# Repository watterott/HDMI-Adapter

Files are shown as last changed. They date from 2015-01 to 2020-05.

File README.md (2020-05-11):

# HDMI-Adapter
Universal HDMI/DVI Displays with Touch Panel based on an Adapter with TI TFP401 and Microchip ATmega32u4.

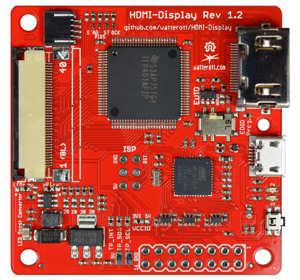
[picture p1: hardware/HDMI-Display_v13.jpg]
HDMI-Adapter


* [TI TFP401A](https://www.ti.com/product/TFP401A) HDMI to RGB Converter
* HDMI compatible (DVI, no Sound, no HDCP, no CEC)
* [Microchip ATmega32U4](https://www.microchip.com/wwwproducts/en/ATMEGA32U4) Microcontroller to control Backlight and Touch Panel (USB HID Mouse)
* LED Backlight Boost Regulator (up to 35V)
* Single 5V Power Supply via MicroUSB connector
* Open-Source and released under the [Creative Commons Attribution Share-Alike License](https://creativecommons.org/licenses/by-sa/4.0/).
* **[Documentation on learn.watterott.com](https://learn.watterott.com)**

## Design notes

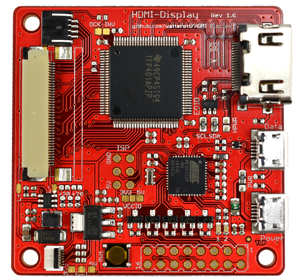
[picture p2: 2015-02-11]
hardware/HDMI-Display_v10.jpg

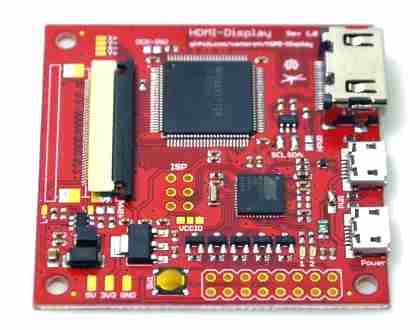
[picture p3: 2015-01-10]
hardware/HDMI-Display_v10dev.jpg

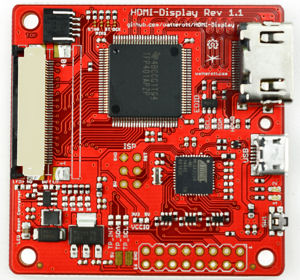
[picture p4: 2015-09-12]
hardware/HDMI-Display_v11.jpg

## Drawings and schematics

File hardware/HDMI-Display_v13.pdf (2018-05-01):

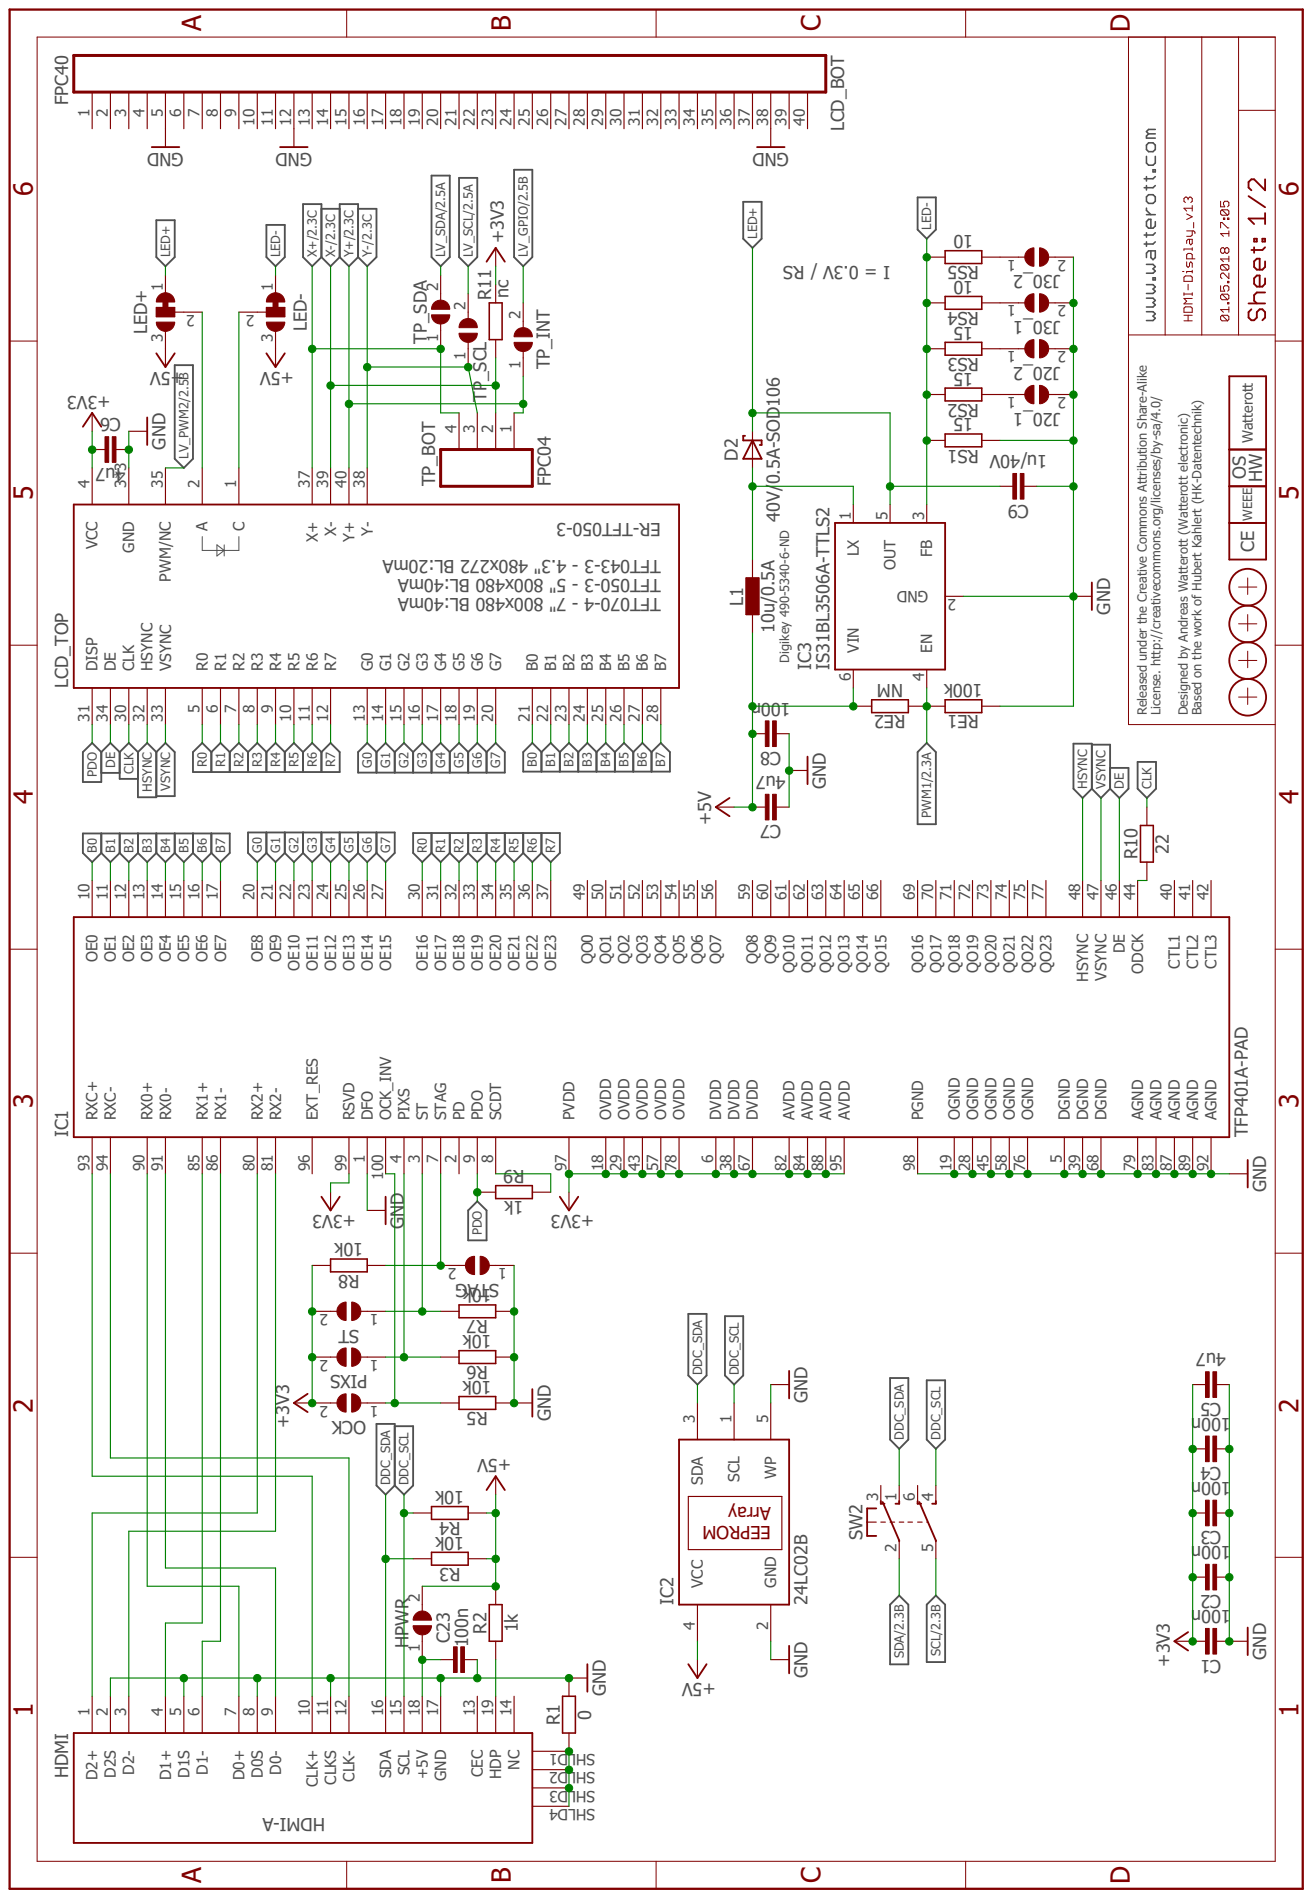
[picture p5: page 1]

Released under the Creative Commons Attribution Share-Alike

License. http://creativecommons.org/licenses/by-sa/4.0/ Designed by Andreas Watterott (Watterott electronic) Based on the work of Hubert Kahlert (HK-Datentechnik)

Watterott WEEE CE OS HW

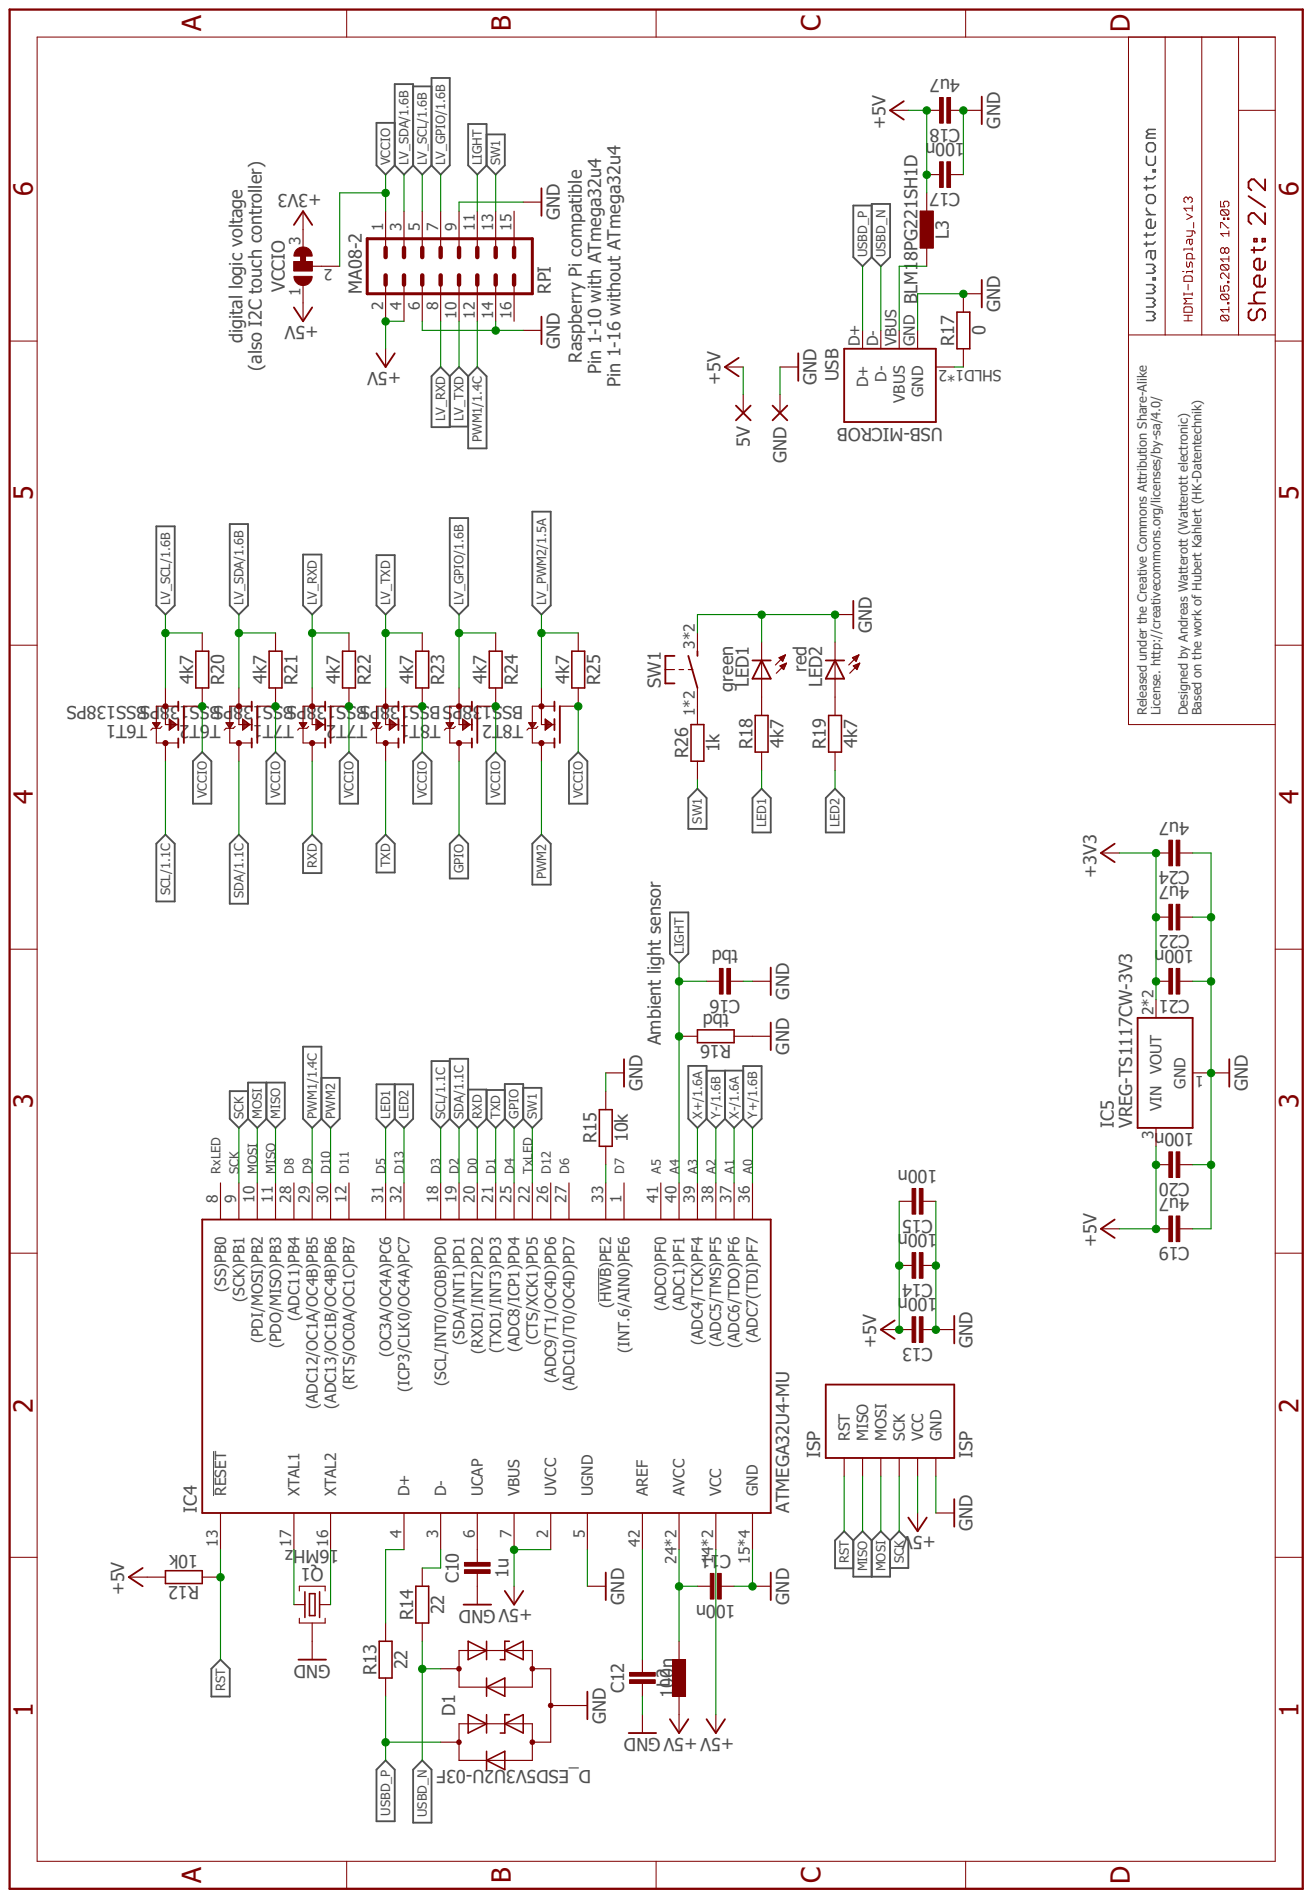
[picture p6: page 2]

mbient light sensor Raspberry Pi compatible Pin 1-10 with ATmega32u4 Pin 1-16 without ATmega32u4

Released under the Creative Commons Attribution Share-Alike

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

ST MISO MOSI SCK VCC GND

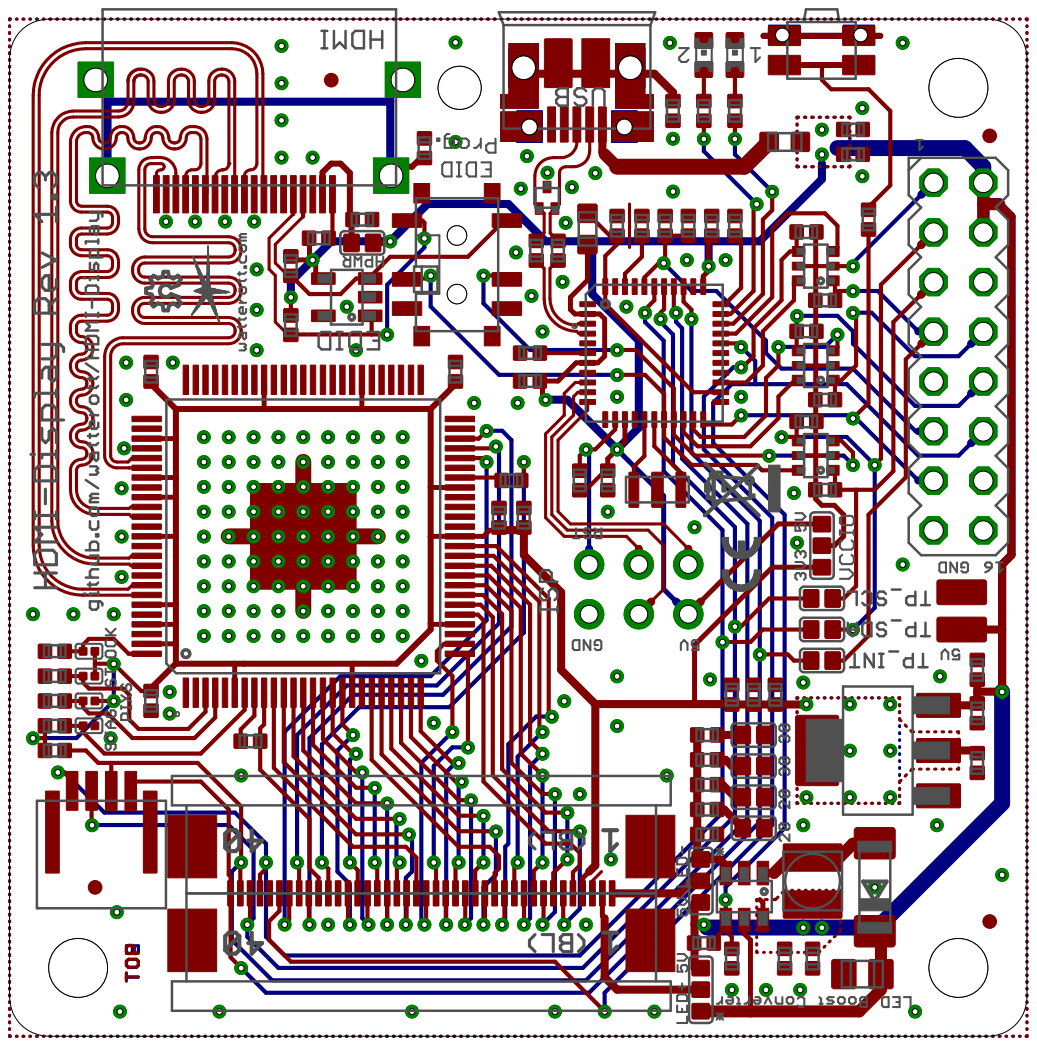
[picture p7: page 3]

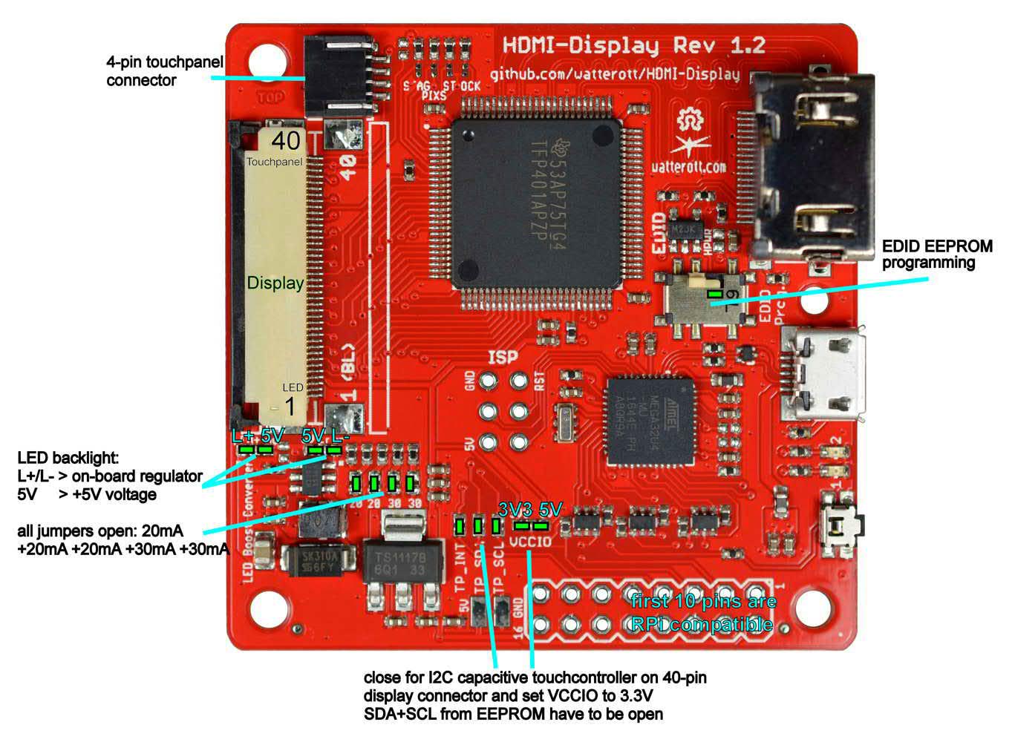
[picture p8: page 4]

Jumper | LED+ LED- VCCIO TP_SDA TP_SCL TP_INT
Displays with resistive Touchpanel
(no Backlight Boost Regulator) | LED+ LED-

3.3V
or
5V
open | open | open

Displays with capacitive Touchpanel
(on-board Backlight Boost Regulator) | 5V | 5V | 3.3V | closed | closed closed

The adapter is pre-programmed with the respective firmware for a resistive (RTP) or capacitive (CTP) Touchpanel. But the EDID EEPROM is empty.
To program EDID data into the EEPROM the switch has to be set to the marked direction and HDMI has to be disconnected during the programming. The programming can be started, when the tactile switch SW1 is hold on power-up.

The backlight brightness of the Displays with capacitive Touchpanel can be controlled via Pin 35 (AVR PB6).

Displays with resistive Touchpanel: TFT043-3, TFT050-3, TFT070-4

Displays with capacitive Touchpanel: HY050CTP-HD, HY070CTP, HY070CTP-HD, HY101CTP

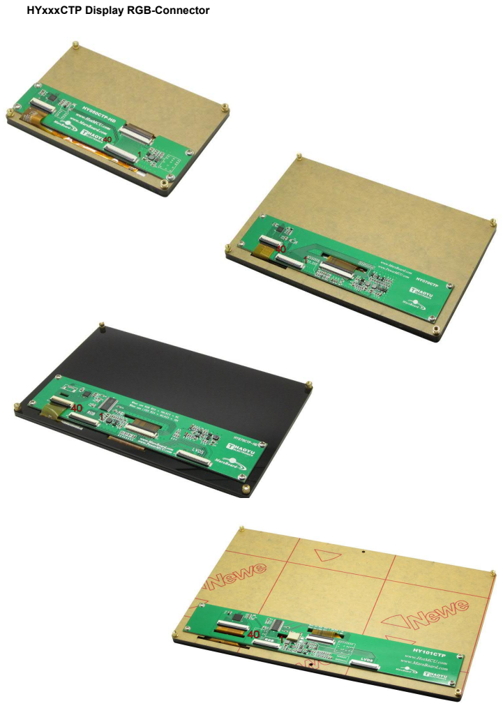
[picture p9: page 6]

HYxxxCTP Display RGB-Connector

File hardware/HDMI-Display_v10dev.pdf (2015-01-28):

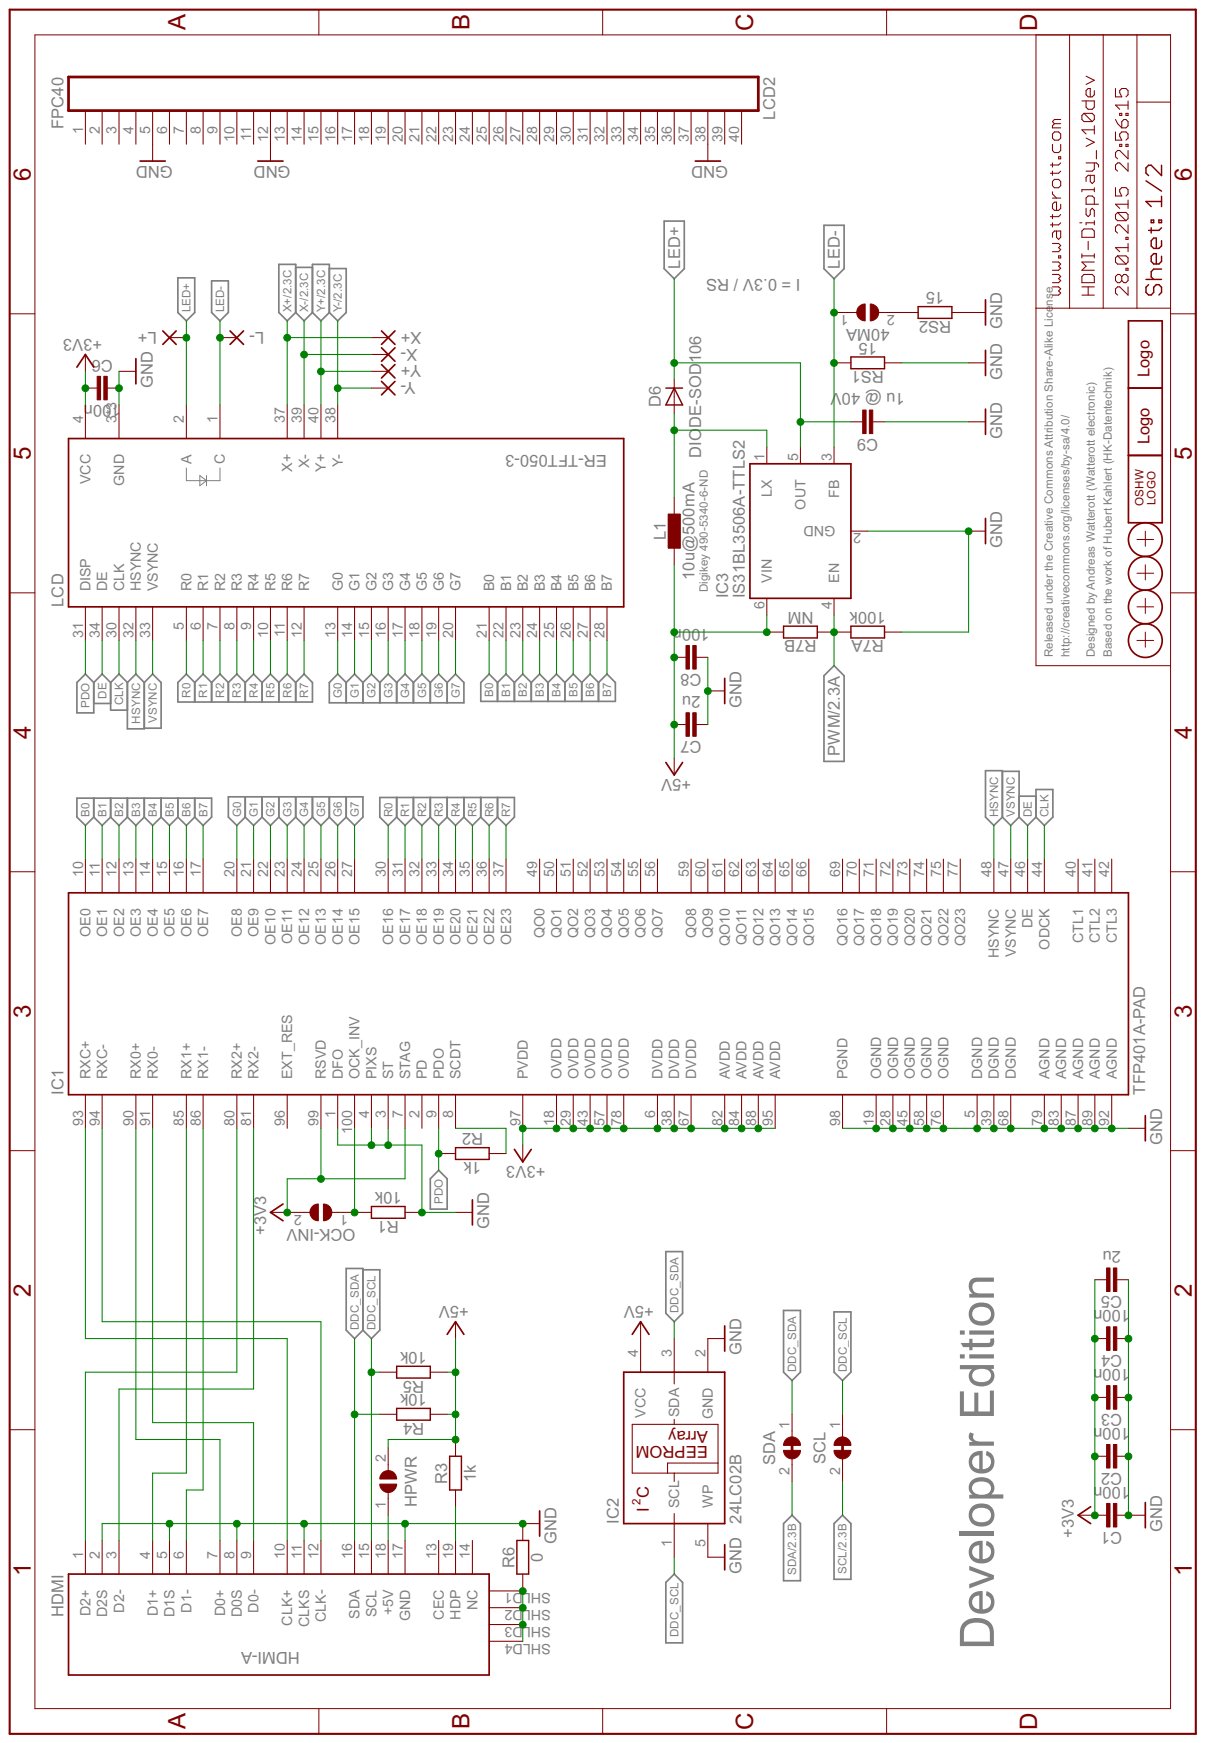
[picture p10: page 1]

Released under the Creative Commons Attribution Share-Alike License

Based on the work of Hubert Kahlert (HK-Datentechnik)

Designed by Andreas Watterott (Watterott electronic)

http://creativecommons.org/licenses/by-sa/4.0/

VSYNC 33 HSYNC 32 CLK 30 DE 34

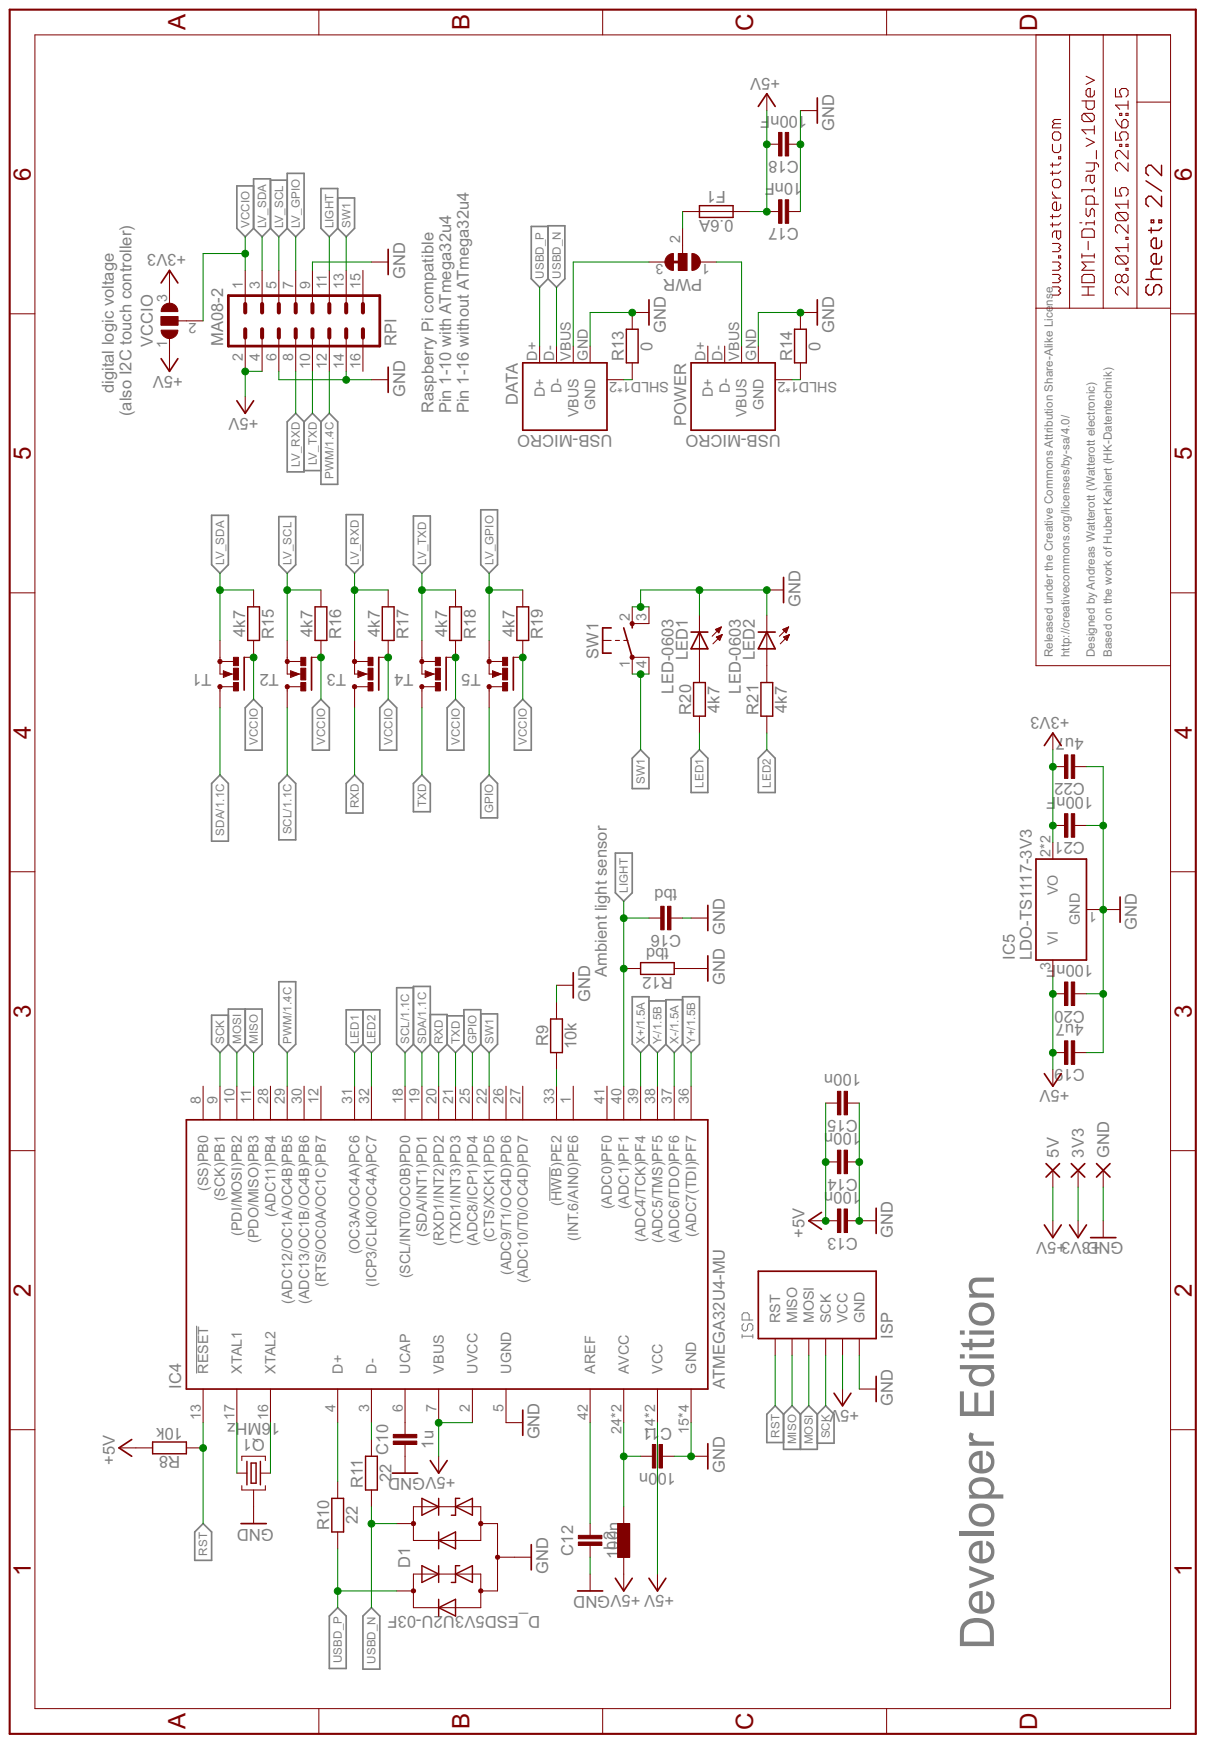
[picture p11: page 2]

(PDO/MISO)PB3 11 (PDI/MOSI)PB2 10 (SCK)PB1 9 (SS)PB0 8

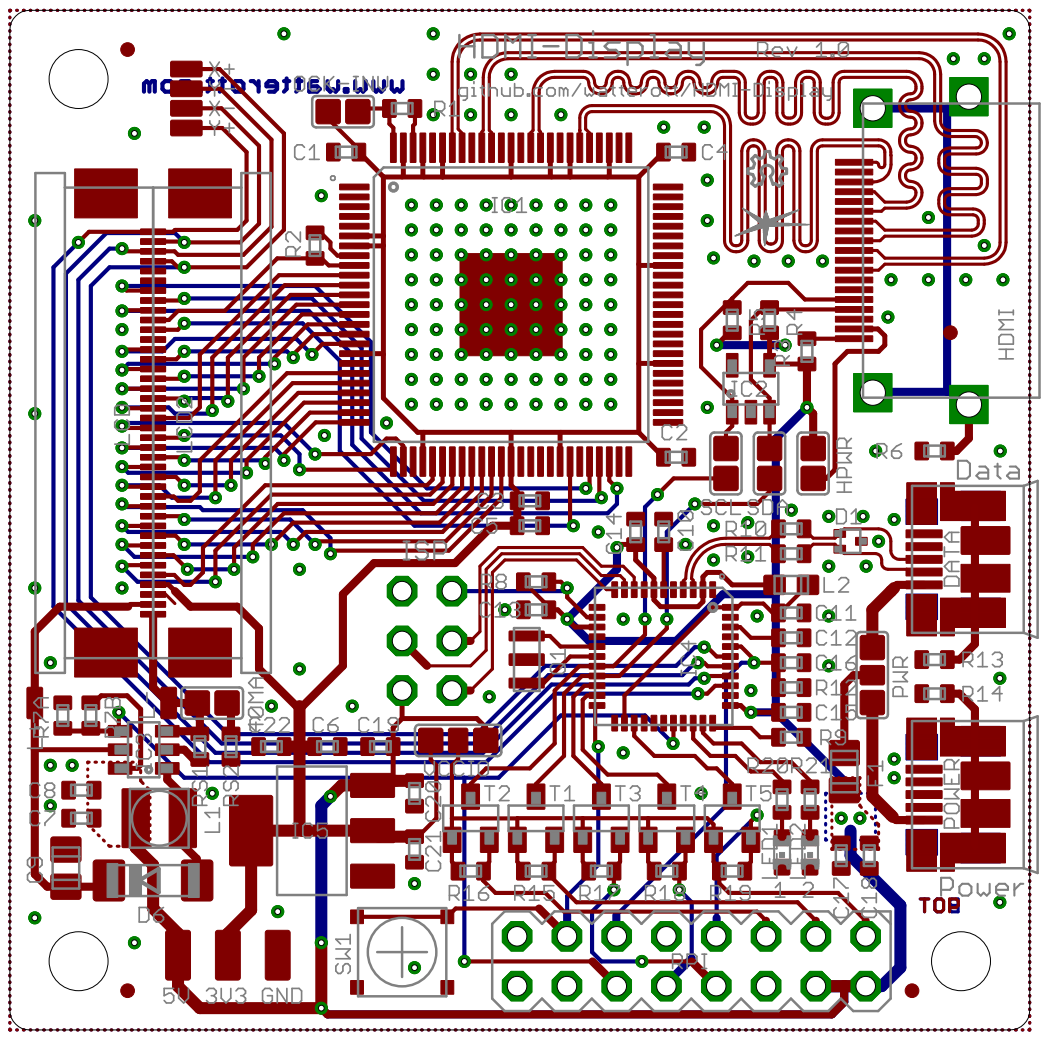
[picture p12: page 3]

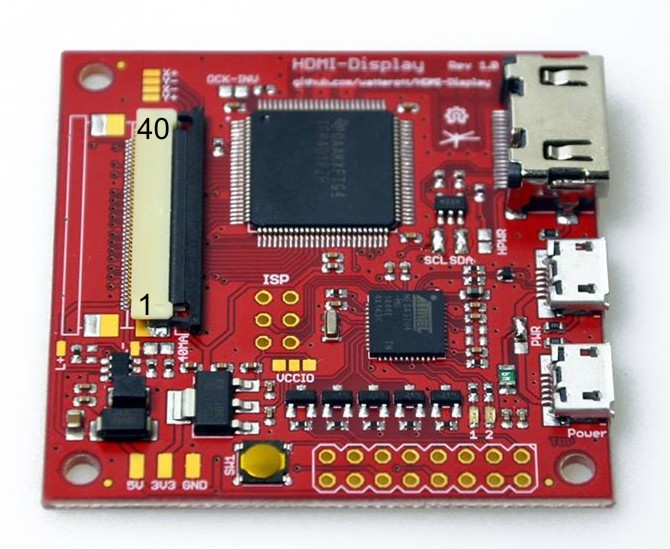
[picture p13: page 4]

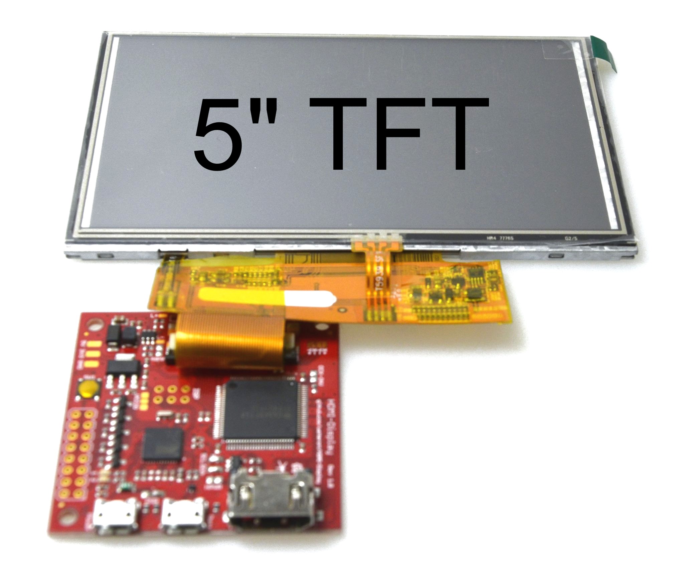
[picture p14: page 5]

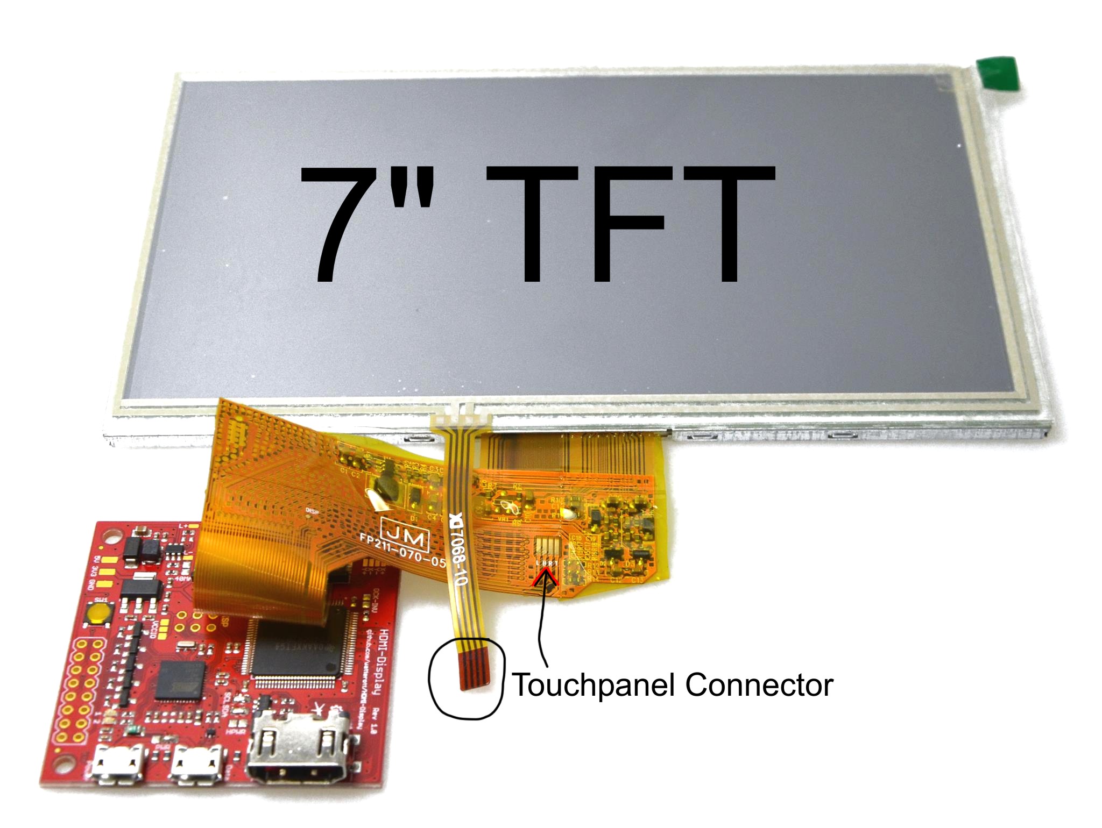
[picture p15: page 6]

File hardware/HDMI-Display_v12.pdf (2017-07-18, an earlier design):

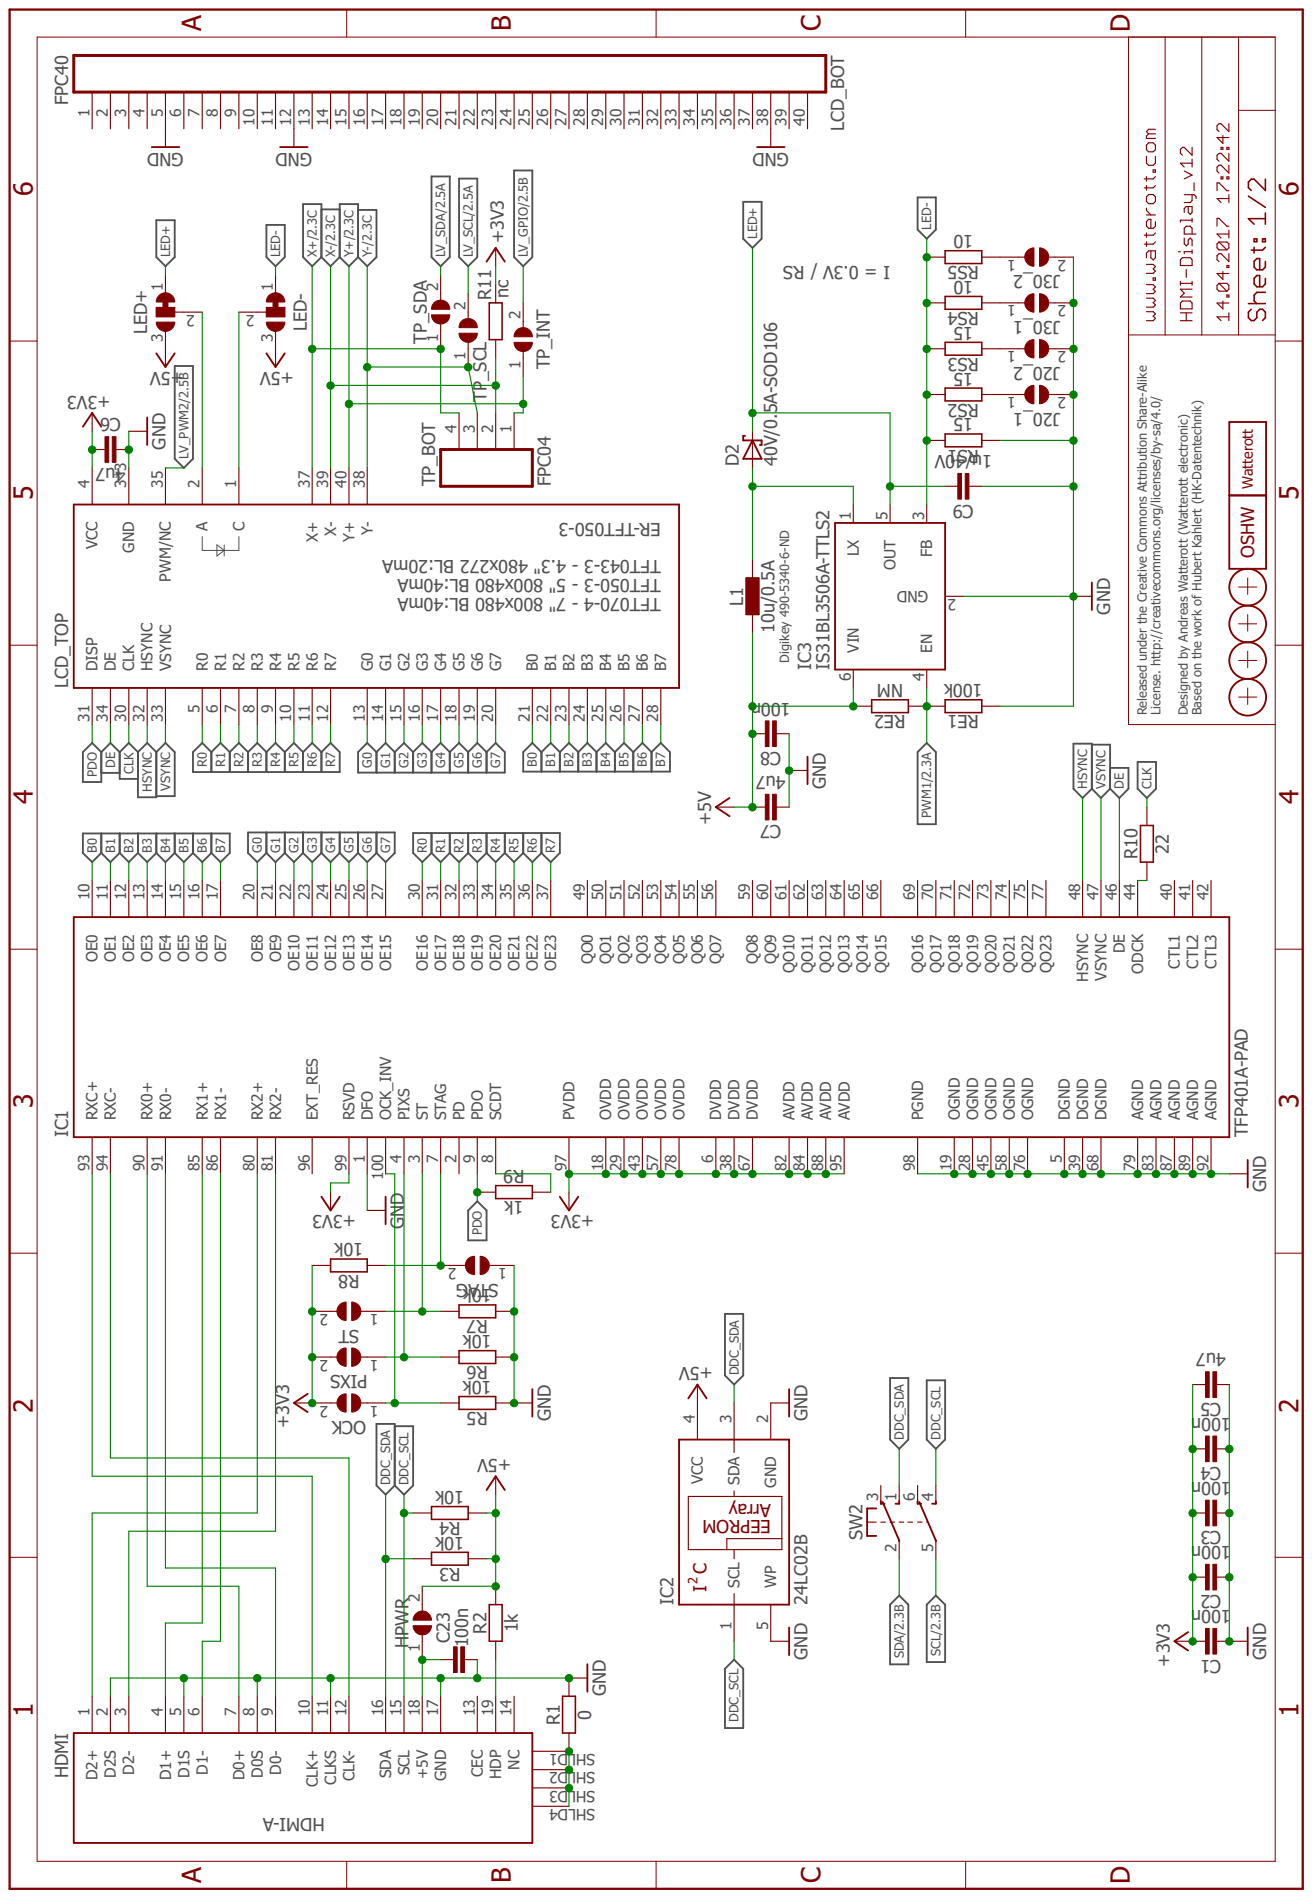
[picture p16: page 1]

Released under the Creative Commons At ribution Share-Alike

License. http://creativecommons.org/licenses/by-sa/4.0/ Designed by Andreas Watterott (Watterott electronic) Based on the work of Hubert Kahlert (HK-Datentechnik)


mbient light sensor Raspberry Pi compatible Pin 1-10 with ATmega32u4 Pin 1-16 without ATmega32u4

Released under the Creative Commons At ribution Share-Alike License http://creativecommons.org/licenses/by-sa/4.0/ Designed by Andreas Watterott (Watterott electronic) Based on the work of Hubert Kahlert (HK-Datentechnik)

ST MISO MOSI SCK VCC GND



Jumper | LED+ LED- VCCIO TP_SDA TP_SCL TP_INT
Displays with resistive Touchpanel
(no Backlight Boost Regulator) | LED+ LED-

3.3V
or
5V
open | open | open

Displays with capacitive Touchpanel
(on-board Backlight Boost Regulator) | 5V | 5V | 3.3V | closed | closed closed

The adapter is pre-programmed with the respective firmware for a resistive (RTP) or capacitive (CTP) Touchpanel. But the EDID EEPROM is empty.
To program EDID data into the EEPROM the switch has to be set to the marked direction and HDMI has to be disconnected during the programming. The programming can be started, when the tactile switch SW1 is hold on power-up.

The backlight brightness of the Displays with capacitive Touchpanel can be controlled via Pin 35 (AVR PB6).

Displays with resistive Touchpanel: TFT043-3, TFT050-3, TFT070-4

Displays with capacitive Touchpanel: HY050CTP-HD, HY070CTP, HY070CTP-HD, HY101CTP


HYxxxCTP Display RGB-Connector

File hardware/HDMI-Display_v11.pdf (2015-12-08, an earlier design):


Released under the Creative Commons Attribution Share-Alike License http://creativecommons.org/licenses/by-sa/4.0/ Designed by Andreas Watterott (Watterott electronic) Based on the work of Hubert Kahlert (HK-Datentechnik)


Raspberry Pi compatible Pin 1-10 with ATmega32u4 Pin 1-16 without ATmega32u4

GND USB ORCI M- BS U

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

ST MISO MOSI SCK VCC GND



Jumper | LED+ LED- VCCIO TP_SDA TP_SCL TP_INT

# Displays with resistive Touchpanel

(no Backlight Boost Regulator) | LED+ LED-

3.3V
or
5V
open | open | open

# Displays with capacitive Touchpanel

(on-board Backlight Boost Regulator) | 5V | 5V | 3.3V | closed | closed closed

# To program EDID data into the EEPROM the jumpers SDA + SCL have to be closed and

HDMI has to be disconnected during the programming.

# The backlight brightness of the Displays with capacitive Touchpanel can be controlled via

Pin 35 (AVR PB6).

# Displays with resistive Touchpanel: TFT043-3, TFT050-3, TFT070-4

Displays with capacitive Touchpanel: HY050CTP-HD, HY070CTP, HY070CTP-HD,

# HY101CTP


HYxxxCTP Display RGB-Connector

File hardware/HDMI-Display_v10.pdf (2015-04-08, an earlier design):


Released under the Creative Commons Attribution Share-Alike License

Based on the work of Hubert Kahlert (HK-Datentechnik)

Designed by Andreas Watterott (Watterott electronic)

http://creativecommons.org/licenses/by-sa/4.0/

VSYNC 33 HSYNC 32 CLK 30 DE 34


(PDO/MISO)PB3 11 (PDI/MOSI)PB2 10 (SCK)PB1 9 (SS)PB0 8





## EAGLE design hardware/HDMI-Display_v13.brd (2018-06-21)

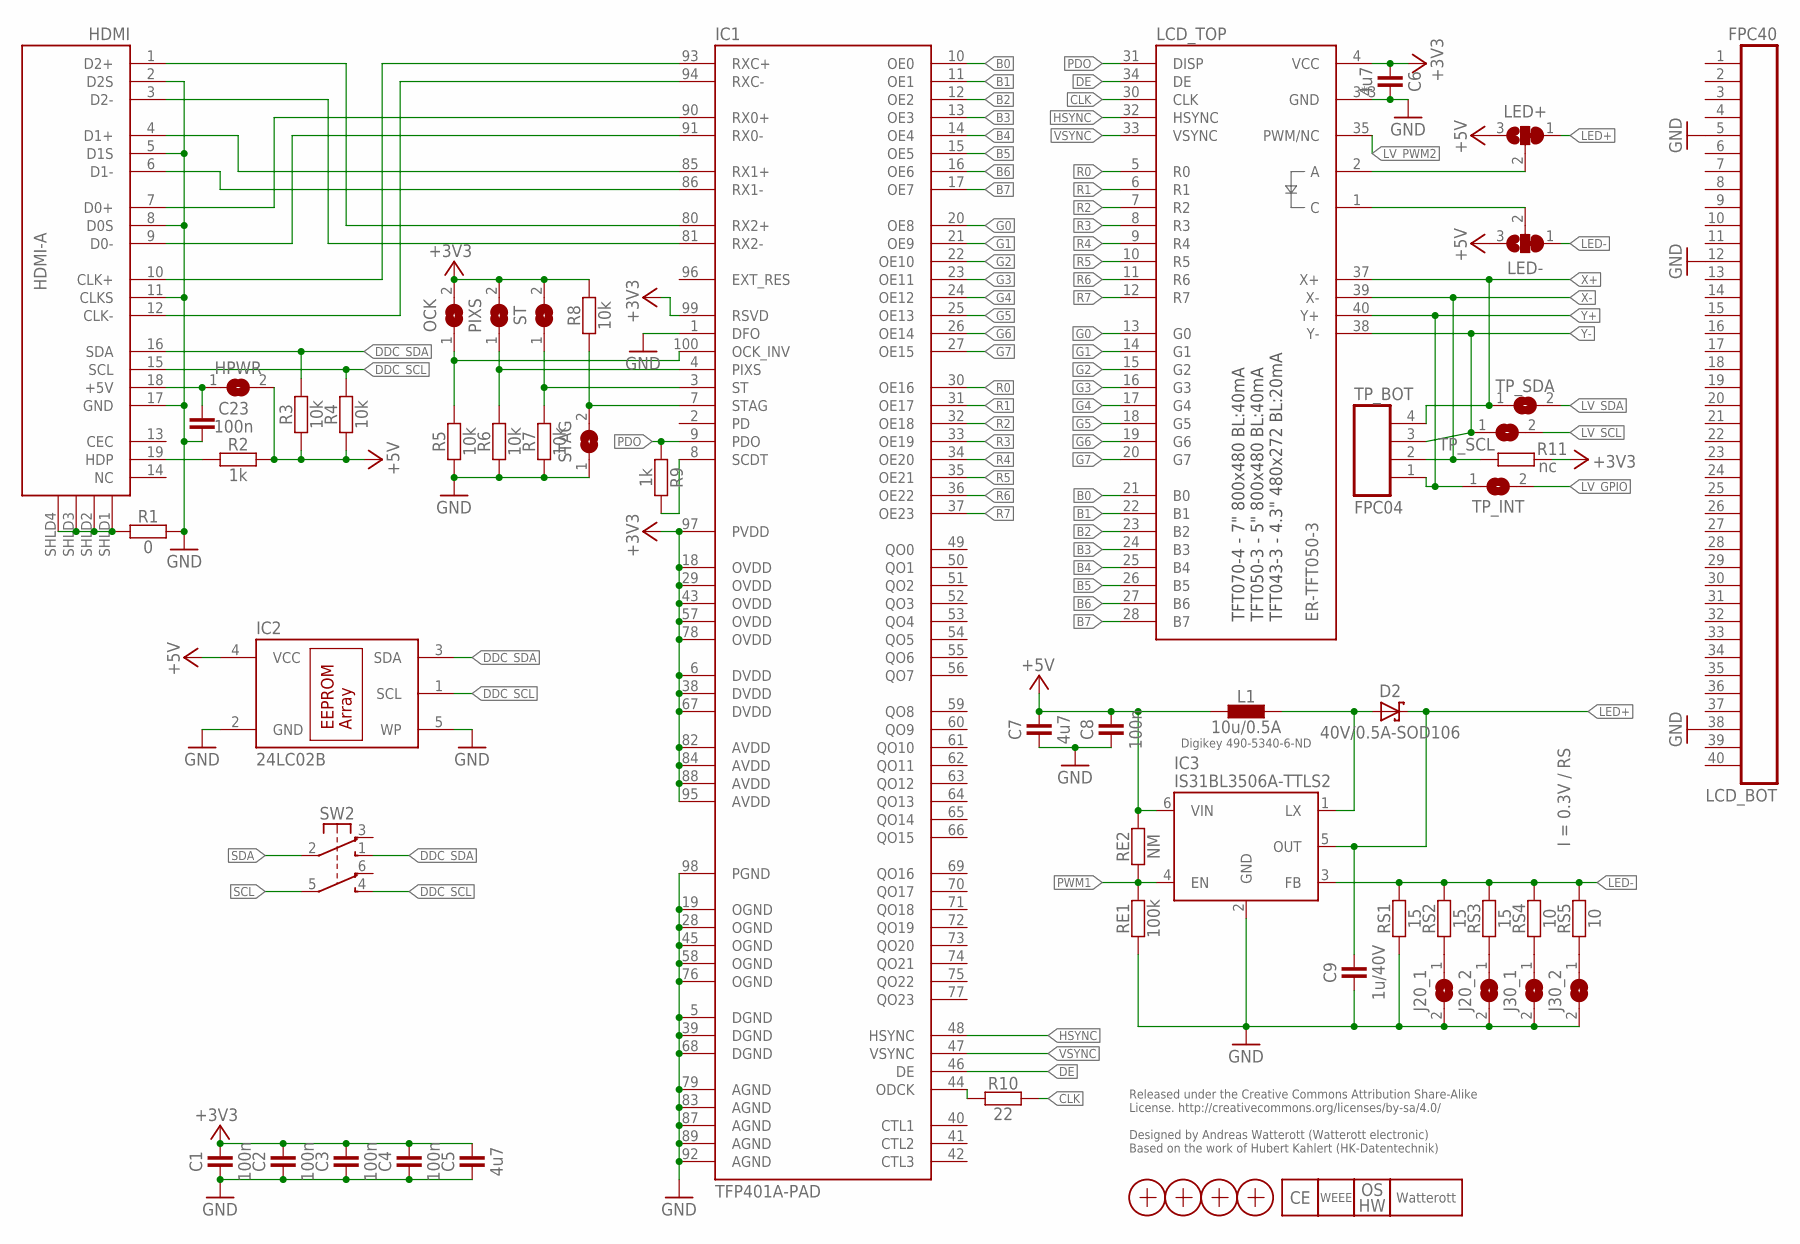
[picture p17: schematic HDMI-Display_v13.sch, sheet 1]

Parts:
C1, C2, C3, C4, C8, C23: 100n; C0402
C5, C6, C7: 4u7; C0402
C9: 1u/40V; C0805
D2: 40V/0.5A-SOD106; SOD106
HDMI: HDMI-A; HDMI_10029449
HPWR: JUMPER2-0402
IC1: TFP401A-PAD; TQFP100-PAD
IC2: 24LC02B; SOT23-5
IC3: IS31BL3506A-TTLS2; SOT23-6
J20_1, J20_2, J30_1, J30_2: JUMPER2-0402
L1: 10u/0.5A; L_1212
LCD_BOT: FPC40; FPC40-0.5
LCD_TOP: ER-TFT050-3; FPC40
LED+: JUMPER3-0402
LED-: JUMPER3-0402
LOGO2: LOGO_SPARK-2; SPARK_2MM
LOGO4: LOGO_WEEE-4; WEEE_4MM
LOGO5: LOGO_CE-2; CE_2MM
LOGO6: LOGO_OSHW-2; OSHW_2MM
OCK: JUMPER2-0201-NC; JUMPER2-0201_NC
PIXS: JUMPER2-0201-NC; JUMPER2-0201_NC
R1: 0; C0402
R2, R9: 1k; C0402
R3, R4, R5, R6, R7, R8: 10k; C0402
R10: 22; C0402
R11: nc; C0402
RE1: 100k; C0402
RE2: NM; C0402
RS1, RS2, RS3: 15; C0402
RS4, RS5: 10; C0402
ST: JUMPER2-0201-NC; JUMPER2-0201_NC
STAG: JUMPER2-0201-NC; JUMPER2-0201_NC
SW2: SW-2UM-CUS22B; CUS22B
TP_BOT: FPC04; FPC04-1.0
TP_INT: JUMPER2-0402
TP_SCL: JUMPER2-0402
TP_SDA: JUMPER2-0402
X1, X2, X3, X4: PASSER-07; PASSER_07MM

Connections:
+3V3: C1.2, C2.2, C3.2, C4.2, C5.2, C6.1, IC1.6 (DVDD), IC1.18 (OVDD), IC1.29 (OVDD), IC1.38 (DVDD), IC1.43 (OVDD), IC1.57 (OVDD), IC1.67 (DVDD), IC1.78 (OVDD), IC1.82 (AVDD), IC1.84 (AVDD), IC1.88 (AVDD), IC1.95 (AVDD), IC1.97 (PVDD), IC1.99 (RSVD), LCD_TOP.4 (VCC), OCK.2, PIXS.2, R8.2, R11.2, ST.2; also elsewhere on the board
+5V: C7.2, C8.2, HPWR.2, IC2.4 (VCC), IC3.6 (VIN), L1.1, LED+.3, LED-.3, R2.2, R3.1, R4.1, RE2.2; also elsewhere on the board
B0: IC1.10 (OE0), LCD_TOP.21 (B0)
B1: IC1.11 (OE1), LCD_TOP.22 (B1)
B2: IC1.12 (OE2), LCD_TOP.23 (B2)
B3: IC1.13 (OE3), LCD_TOP.24 (B3)
B4: IC1.14 (OE4), LCD_TOP.25 (B4)
B5: IC1.15 (OE5), LCD_TOP.26 (B5)
B6: IC1.16 (OE6), LCD_TOP.27 (B6)
B7: IC1.17 (OE7), LCD_TOP.28 (B7)
CLK: LCD_TOP.30 (CLK), R10.2
CLK_N: HDMI.12 (CLK-), IC1.94 (RXC-)
CLK_P: HDMI.10 (CLK+), IC1.93 (RXC+)
D0_N: HDMI.9 (D0-), IC1.91 (RX0-)
D0_P: HDMI.7 (D0+), IC1.90 (RX0+)
D1_N: HDMI.6 (D1-), IC1.86 (RX1-)
D1_P: HDMI.4 (D1+), IC1.85 (RX1+)
D2_N: HDMI.3 (D2-), IC1.81 (RX2-)
D2_P: HDMI.1 (D2+), IC1.80 (RX2+)
DDC_SCL: HDMI.15 (SCL), IC2.1 (SCL), R4.2, SW2.4 (S2)
DDC_SDA: HDMI.16 (SDA), IC2.3 (SDA), R3.2, SW2.1 (S1)
DE: IC1.46 (DE), LCD_TOP.34 (DE)
G0: IC1.20 (OE8), LCD_TOP.13 (G0)
G1: IC1.21 (OE9), LCD_TOP.14 (G1)
G2: IC1.22 (OE10), LCD_TOP.15 (G2)
G3: IC1.23 (OE11), LCD_TOP.16 (G3)
G4: IC1.24 (OE12), LCD_TOP.17 (G4)
G5: IC1.25 (OE13), LCD_TOP.18 (G5)
G6: IC1.26 (OE14), LCD_TOP.19 (G6)
G7: IC1.27 (OE15), LCD_TOP.20 (G7)
GND: C1.1, C2.1, C3.1, C4.1, C5.1, C6.2, C7.1, C8.1, C9.1, C23.1, HDMI.2 (D2S), HDMI.5 (D1S), HDMI.8 (D0S), HDMI.11 (CLKS), HDMI.17 (GND), IC1.1 (DFO), IC1.5 (DGND), IC1.19 (OGND), IC1.28 (OGND), IC1.39 (DGND), IC1.45 (OGND), IC1.58 (OGND), IC1.68 (DGND), IC1.76 (OGND), IC1.79 (AGND), IC1.83 (AGND), IC1.87 (AGND), IC1.89 (AGND), IC1.92 (AGND), IC1.98 (PGND), IC2.2 (GND), IC2.5 (WP), IC3.2 (GND), J20_1.2, J20_2.2, J30_1.2, J30_2.2, LCD_BOT.5, LCD_BOT.12, LCD_BOT.38, LCD_TOP.3 (GND), LCD_TOP.29 (GND), LCD_TOP.36 (GND), R1.1, R5.1, R6.1, R7.1, RE1.1, RS1.1, STAG.1; also elsewhere on the board
HDMI_5V: C23.2, HDMI.18 (+5V), HPWR.1
HDMI_DECT: HDMI.19 (HDP), R2.1
HSYNC: IC1.48 (HSYNC), LCD_TOP.32 (HSYNC)
LED+: C9.2, D2.C, IC3.5 (OUT), LED+.1
LED-: IC3.3 (FB), LED-.1, RS1.2, RS2.2, RS3.2, RS4.2, RS5.2
LEDA: LCD_TOP.2 (A), LED+.2
LEDC: LCD_TOP.1 (C), LED-.2
LV_GPIO: TP_INT.2; also elsewhere on the board
LV_PWM2: LCD_TOP.35 (PWM/NC); also elsewhere on the board
LV_SCL: TP_SCL.2; also elsewhere on the board
LV_SDA: TP_SDA.2; also elsewhere on the board
LX: D2.A, IC3.1 (LX), L1.2
unnamed: J20_2.1, RS3.1
unnamed: IC1.44 (ODCK), R10.1
unnamed: J30_1.1, RS4.1
unnamed: J20_1.1, RS2.1
unnamed: J30_2.1, RS5.1
OCKINV: IC1.100 (OCK_INV), OCK.1, R5.2
PDO: IC1.9 (PDO), LCD_TOP.31 (DISP), R9.1
PIXS: IC1.4 (PIXS), PIXS.1, R6.2
PWM1: IC3.4 (EN), RE1.2, RE2.1; also elsewhere on the board
R0: IC1.30 (OE16), LCD_TOP.5 (R0)
R1: IC1.31 (OE17), LCD_TOP.6 (R1)
R2: IC1.32 (OE18), LCD_TOP.7 (R2)
R3: IC1.33 (OE19), LCD_TOP.8 (R3)
R4: IC1.34 (OE20), LCD_TOP.9 (R4)
R5: IC1.35 (OE21), LCD_TOP.10 (R5)
R6: IC1.36 (OE22), LCD_TOP.11 (R6)
R7: IC1.37 (OE23), LCD_TOP.12 (R7)
SCDT: IC1.8 (SCDT), R9.2
SCL: SW2.5 (P2); also elsewhere on the board
SDA: SW2.2 (P1); also elsewhere on the board
SHLD3: HDMI.SHLD1 (SHLD), HDMI.SHLD2 (SHLD), HDMI.SHLD3 (SHLD), HDMI.SHLD4 (SHLD), R1.2
ST: IC1.3 (ST), R7.2, ST.1
STAG: IC1.7 (STAG), R8.1, STAG.2
VSYNC: IC1.47 (VSYNC), LCD_TOP.33 (VSYNC)
X+: LCD_TOP.37 (X+), TP_BOT.4, TP_SDA.1; also elsewhere on the board
X-: LCD_TOP.39 (X-), R11.1, TP_BOT.2; also elsewhere on the board
Y+: LCD_TOP.40 (Y+), TP_BOT.1, TP_INT.1; also elsewhere on the board
Y-: LCD_TOP.38 (Y-), TP_BOT.3, TP_SCL.1; also elsewhere on the board

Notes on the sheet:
I = 0.3V / RS
Digikey 490-5340-6-ND
Released under the Creative Commons Attribution Share-Alike License. http://creativecommons.org/licenses/by-sa/4.0/ Designed by Andreas Watterott (Watterott electronic) Based on the work of Hubert Kahlert (HK-Datentechnik)
TFT070-4 - 7" 800x480 BL:40mA TFT050-3 - 5" 800x480 BL:40mA TFT043-3 - 4.3" 480x272 BL:20mA

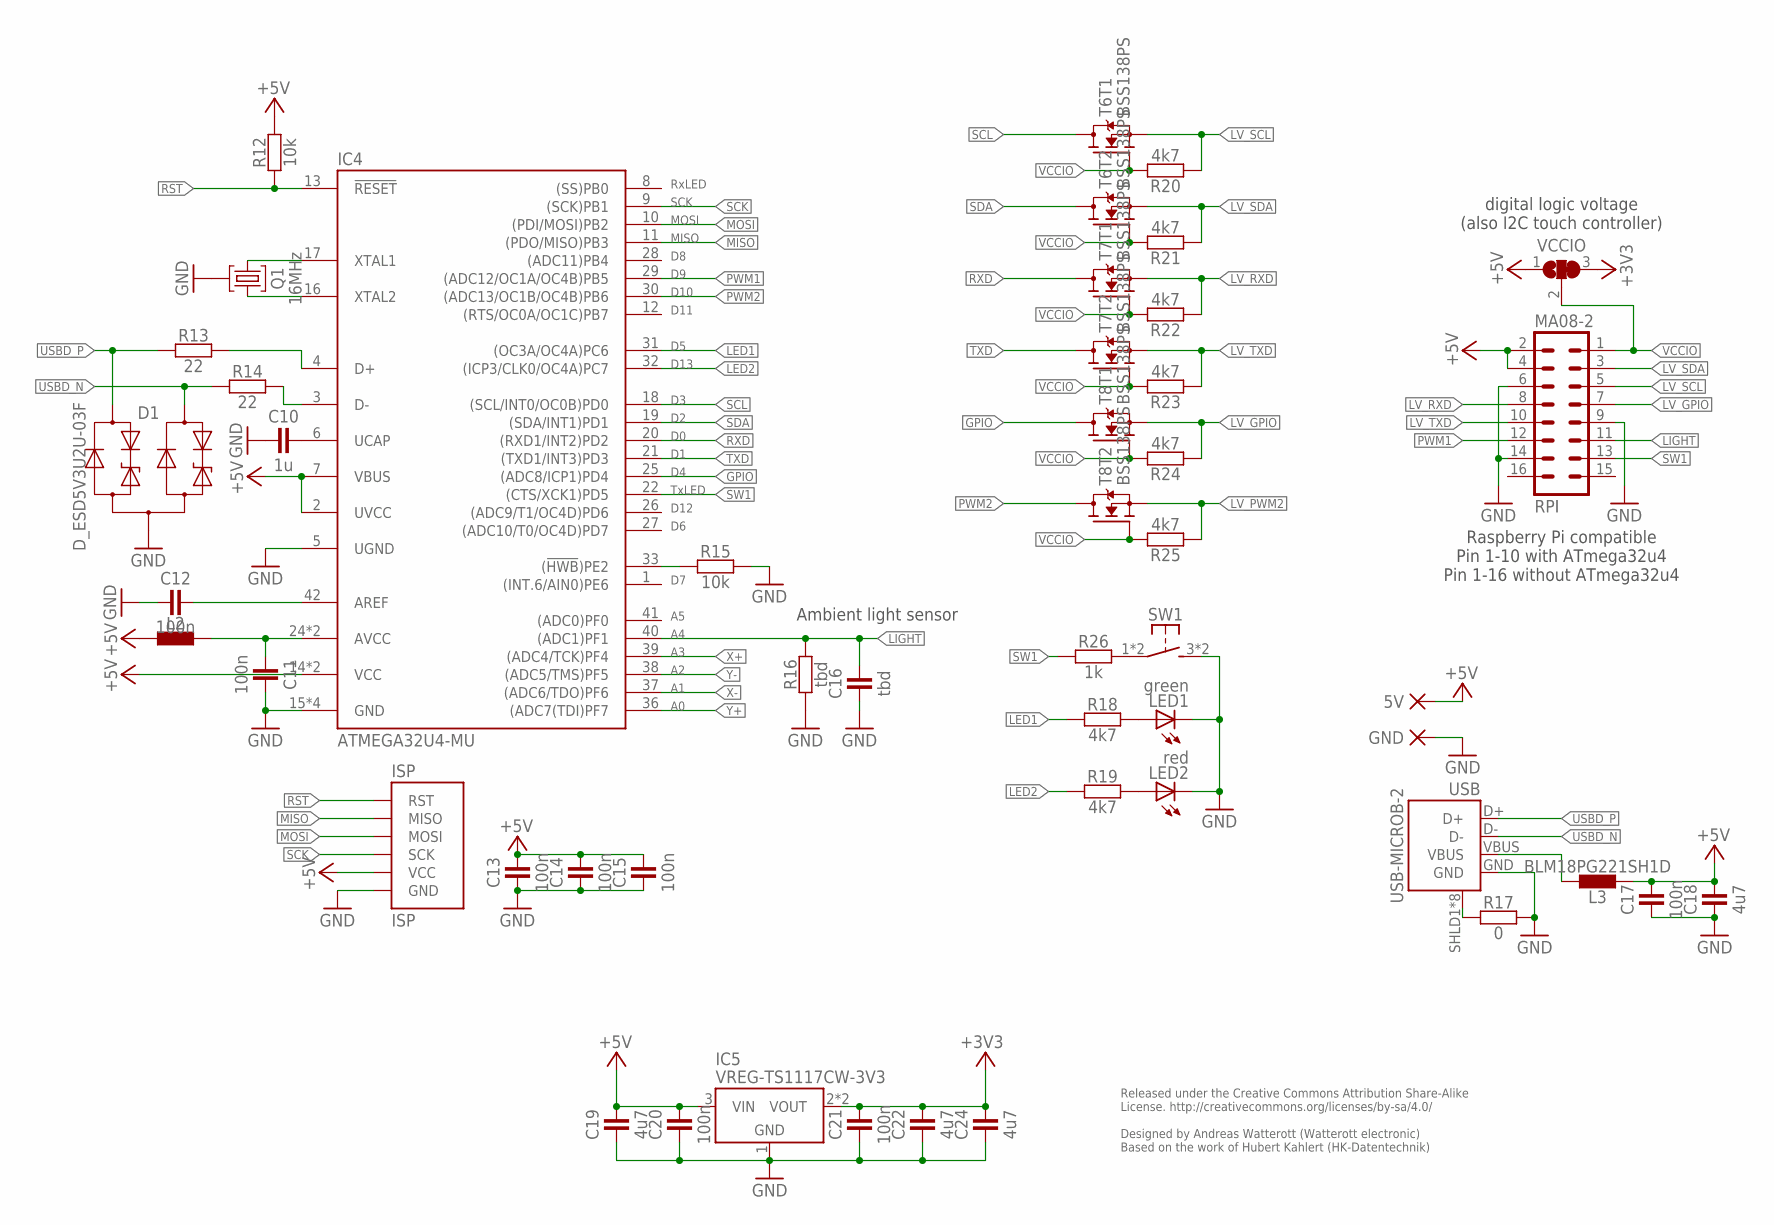
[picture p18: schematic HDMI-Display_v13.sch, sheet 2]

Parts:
5V: PAD-1.27X2.54_NC
C10: 1u; C0402
C11, C12, C13, C14, C15, C17, C20, C21: 100n; C0402
C16: tbd; C0402
C18, C19, C22, C24: 4u7; C0402
D1: D_ESD5V3U2U-03F; SOT723
GND: PAD-1.27X2.54_NC
IC4: ATMEGA32U4-MU; QFN44
IC5: VREG-TS1117CW-3V3; SOT223
ISP: ISP; ISP-2X3
L2: INDUCTOR-0603; C0603
L3: BLM18PG221SH1D; C0603
LED1: green; C0603
LED2: red; C0603
Q1: 16MHz; CRYSTAL_32X13
R12, R15: 10k; C0402
R13, R14: 22; C0402
R16: tbd; C0402
R17: 0; C0402
R18, R19, R20, R21, R22, R23, R24, R25: 4k7; C0402
R26: 1k; C0402
RPI: MA08-2
SW1: SW-TACTILE-PTS840P; PTS840P
T6, T7, T8: BSS138PS; SOT363
USB: USB-MICROB-2; USB-MICROB-10118194
VCCIO: JUMPER3-0402

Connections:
+3V3: C21.2, C22.2, C24.2, IC5.2 (VOUT), IC5.4 (VOUT), VCCIO.3; also elsewhere on the board
+5V: 5V.1, C13.2, C14.2, C15.2, C17.2, C18.2, C19.2, C20.2, IC4.2 (UVCC), IC4.7 (VBUS), IC4.14 (VCC), IC4.34 (VCC), IC5.3 (VIN), ISP.VCC, L2.1, L3.1, R12.2, RPI.2, RPI.4, VCCIO.1; also elsewhere on the board
AREF: C12.2, IC4.42 (AREF)
AVCC: C11.1, IC4.24 (AVCC), IC4.44 (AVCC), L2.2
D_N: IC4.3 (D-), R14.2
D_P: IC4.4 (D+), R13.2
GND: C10.1, C11.2, C12.1, C13.1, C14.1, C15.1, C16.1, C17.1, C18.1, C19.1, C20.1, C21.1, C22.1, C24.1, D1.3 (A), GND.1, IC4.5 (UGND), IC4.15 (GND), IC4.23 (GND), IC4.35 (GND), IC4.43 (GND), IC5.1 (GND), ISP.GND, LED1.C, LED2.C, Q1.GND, R15.2, R16.1, R17.1, RPI.6, RPI.9, RPI.14, SW1.3 (S1), SW1.4 (S1), USB.GND; also elsewhere on the board
GPIO: IC4.25 ((ADC8/ICP1)PD4), T8.6 (D)
HWB: IC4.33 ((!HWB!)PE2), R15.1
LED1: IC4.31 ((OC3A/OC4A)PC6), R18.1
LED2: IC4.32 ((ICP3/CLK0/OC4A)PC7), R19.1
LIGHT: C16.2, IC4.40 ((ADC1)PF1), R16.2, RPI.11
LV_GPIO: R24.1, RPI.7, T8.1 (S); also elsewhere on the board
LV_PWM2: R25.1, T8.4 (S); also elsewhere on the board
LV_RXD: R22.1, RPI.8, T7.1 (S)
LV_SCL: R20.1, RPI.5, T6.1 (S); also elsewhere on the board
LV_SDA: R21.1, RPI.3, T6.4 (S); also elsewhere on the board
LV_TXD: R23.1, RPI.10, T7.4 (S)
MISO: IC4.11 ((PDO/MISO)PB3), ISP.MISO
MOSI: IC4.10 ((PDI/MOSI)PB2), ISP.MOSI
unnamed: R26.2, SW1.1, SW1.2 (P1)
unnamed: LED1.A, R18.2
unnamed: LED2.A, R19.2
PWM1: IC4.29 ((ADC12/OC1A/OC4B)PB5), RPI.12; also elsewhere on the board
PWM2: IC4.30 ((ADC13/OC1B/OC4B)PB6), T8.3 (D)
RST: IC4.13 (!RESET), ISP.RST, R12.1
RXD: IC4.20 ((RXD1/INT2)PD2), T7.6 (D)
SCK: IC4.9 ((SCK)PB1), ISP.SCK
SCL: IC4.18 ((SCL/INT0/OC0B)PD0), T6.6 (D); also elsewhere on the board
SDA: IC4.19 ((SDA/INT1)PD1), T6.3 (D); also elsewhere on the board
SHLD1: R17.2, USB.SHLD1 (SHIELD), USB.SHLD2 (SHIELD), USB.SHLD3 (SHIELD), USB.SHLD4 (SHIELD), USB.SHLD5 (SHIELD), USB.SHLD6 (SHIELD), USB.SHLD7 (SHIELD), USB.SHLD8 (SHIELD)
SW1: IC4.22 ((CTS/XCK1)PD5), R26.1, RPI.13
TXD: IC4.21 ((TXD1/INT3)PD3), T7.3 (D)
UCAP: C10.2, IC4.6 (UCAP)
USBD_N: D1.2 (C2), R14.1, USB.D-
USBD_P: D1.1 (C1), R13.1, USB.D+
VBUS: L3.2, USB.VBUS
VCCIO: R20.2, R21.2, R22.2, R23.2, R24.2, R25.2, RPI.1, T6.2 (G), T6.5 (G), T7.2 (G), T7.5 (G), T8.2 (G), T8.5 (G), VCCIO.2
X+: IC4.39 ((ADC4/TCK)PF4); also elsewhere on the board
X-: IC4.37 ((ADC6/TDO)PF6); also elsewhere on the board
XTAL1: IC4.17 (XTAL1), Q1.2
XTAL2: IC4.16 (XTAL2), Q1.1
Y+: IC4.36 ((ADC7(TDI)PF7); also elsewhere on the board
Y-: IC4.38 ((ADC5/TMS)PF5); also elsewhere on the board

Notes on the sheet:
Ambient light sensor
Released under the Creative Commons Attribution Share-Alike License. http://creativecommons.org/licenses/by-sa/4.0/ Designed by Andreas Watterott (Watterott electronic) Based on the work of Hubert Kahlert (HK-Datentechnik)
TxLED
D12
D13
RxLED
SCK
MOSI
MISO
D10
D11
Raspberry Pi compatible Pin 1-10 with ATmega32u4 Pin 1-16 without ATmega32u4
digital logic voltage (also I2C touch controller)

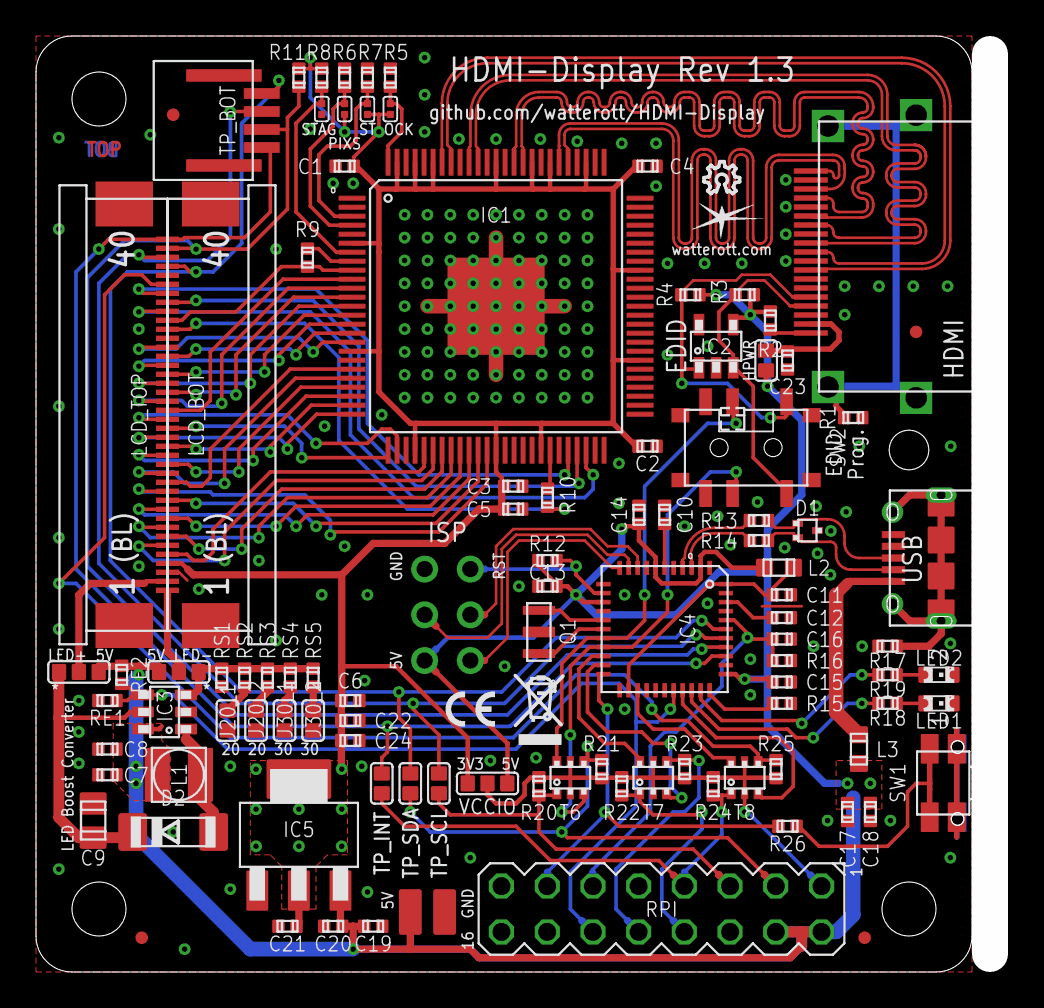
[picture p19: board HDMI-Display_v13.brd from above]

Board: 2 copper layers, 53.0 x 52.0 mm, 107 parts (0 on the bottom side), 101 nets.

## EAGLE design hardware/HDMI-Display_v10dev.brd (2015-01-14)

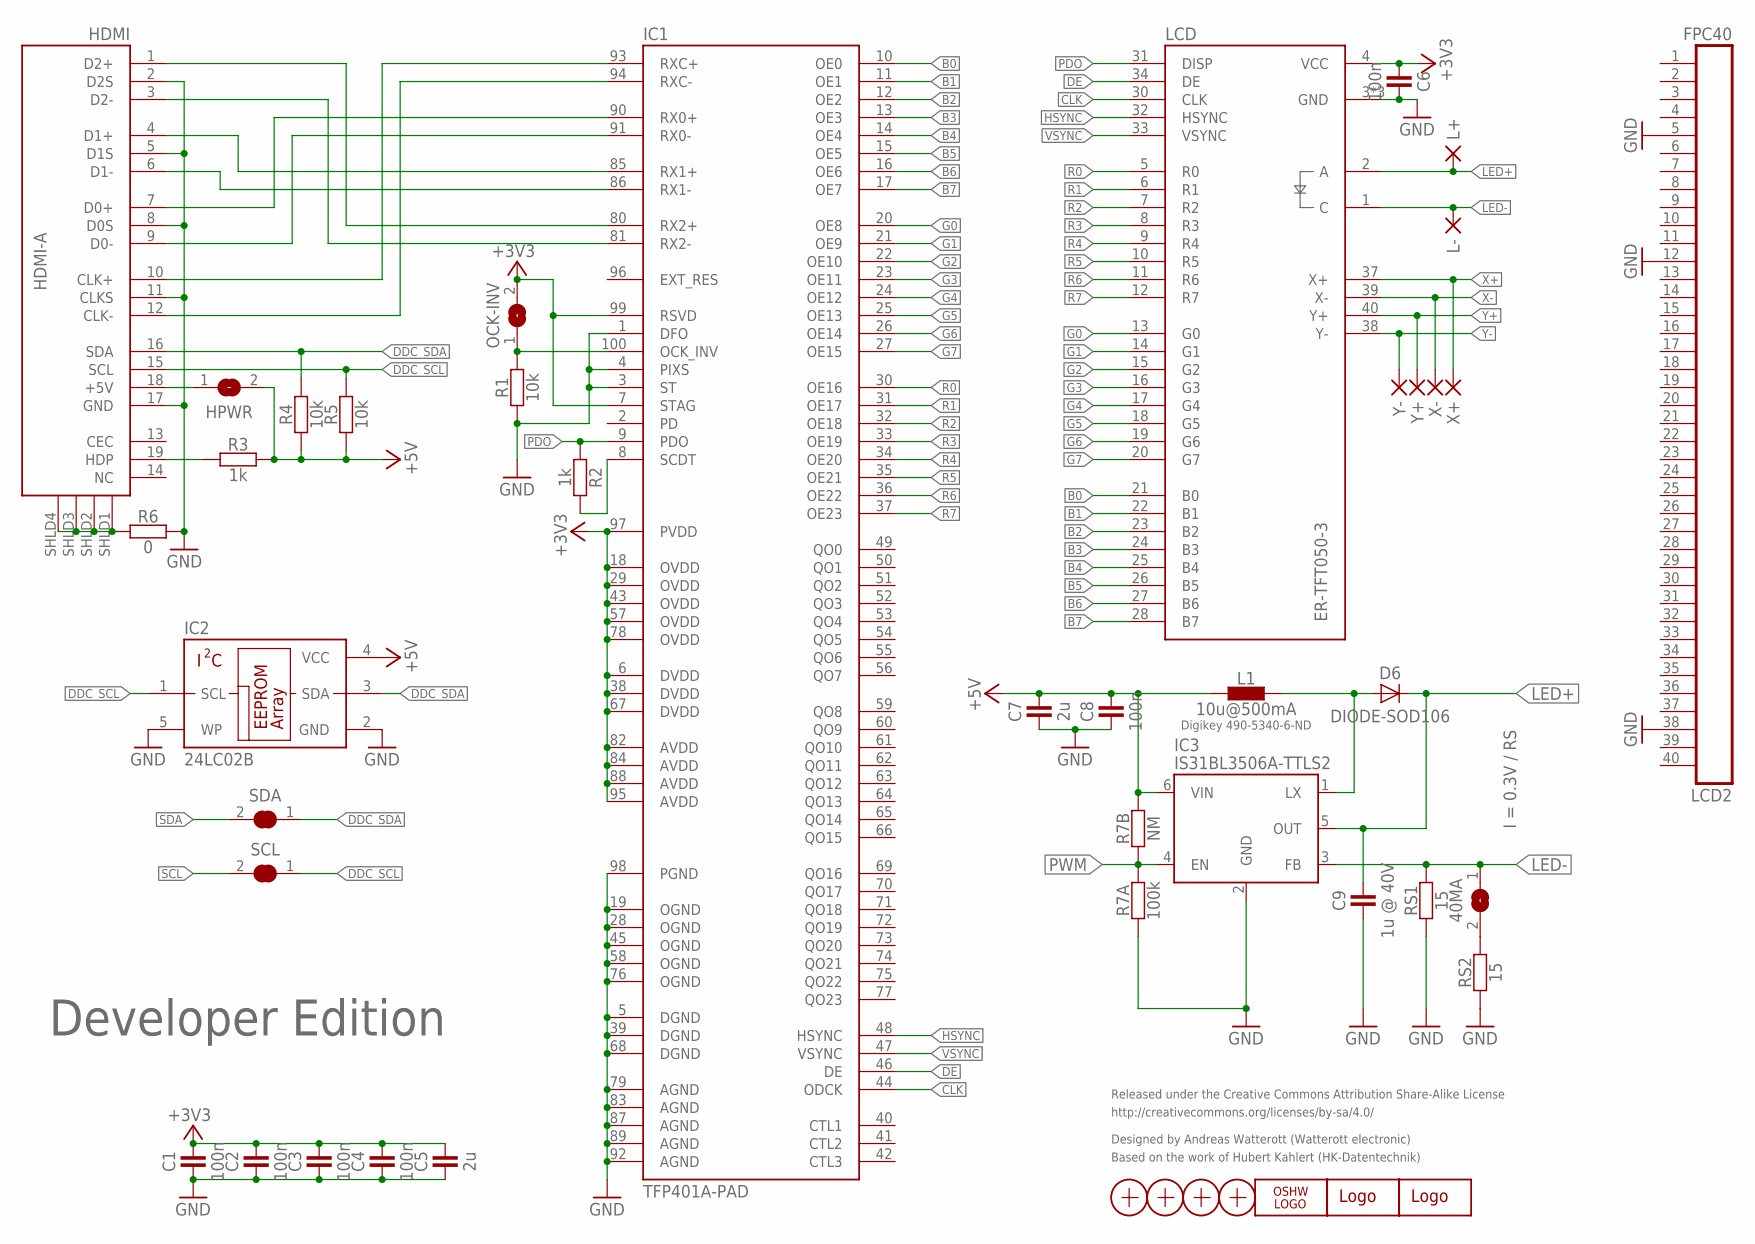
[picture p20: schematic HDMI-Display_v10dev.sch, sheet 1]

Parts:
40MA: JUMPER2
C1, C2, C3, C4, C6, C8: 100n; R0402
C5, C7: 2u; R0402
C9: 1u @ 40V; R0805
D6: DIODE-SOD106; SOD106
HDMI: HDMI-A; HDMI_10029449
HPWR: JUMPER2
IC1: TFP401A-PAD; TQFP100-PAD
IC2: 24LC02B; SOT23-5
IC3: IS31BL3506A-TTLS2; SOT23-6
L1: 10u@500mA; L_1212
L+: PAD-0.80X1.60_NC
L-: PAD-0.80X1.60_NC
LCD: ER-TFT050-3; FPC40
LCD2: FPC40
LOGO1: OSHW_LOGOX0070; OSHW_6X70
LOGO2: LOGO-PLACE; LOGO_TPLACE
LOGO3: LOGO-S_PLACE_S; SPARK_TPLACE_S
OCK-INV: JUMPER2
R1, R4, R5: 10k; R0402
R2, R3: 1k; R0402
R6: 0; R0402
R7A: 100k; R0402
R7B: NM; R0402
RS1, RS2: 15; R0402
SCL: JUMPER2
SDA: JUMPER2
X1, X2, X3, X4: PASSER-07; PASSER_07MM
X+: PAD-0.80X1.60_NC
X-: PAD-0.80X1.60_NC
Y+: PAD-0.80X1.60_NC
Y-: PAD-0.80X1.60_NC

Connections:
+3V3: C1.2, C2.2, C3.2, C4.2, C5.2, C6.1, IC1.6 (DVDD), IC1.7 (STAG), IC1.18 (OVDD), IC1.29 (OVDD), IC1.38 (DVDD), IC1.43 (OVDD), IC1.57 (OVDD), IC1.67 (DVDD), IC1.78 (OVDD), IC1.82 (AVDD), IC1.84 (AVDD), IC1.88 (AVDD), IC1.95 (AVDD), IC1.97 (PVDD), IC1.99 (RSVD), LCD.4 (VCC), OCK-INV.2; also elsewhere on the board
+5V: C7.2, C8.2, HPWR.2, IC2.4 (VCC), IC3.6 (VIN), L1.1, R3.2, R4.1, R5.1, R7B.2; also elsewhere on the board
B0: IC1.10 (OE0), LCD.21 (B0)
B1: IC1.11 (OE1), LCD.22 (B1)
B2: IC1.12 (OE2), LCD.23 (B2)
B3: IC1.13 (OE3), LCD.24 (B3)
B4: IC1.14 (OE4), LCD.25 (B4)
B5: IC1.15 (OE5), LCD.26 (B5)
B6: IC1.16 (OE6), LCD.27 (B6)
B7: IC1.17 (OE7), LCD.28 (B7)
CLK: IC1.44 (ODCK), LCD.30 (CLK)
CLK_N: HDMI.12 (CLK-), IC1.94 (RXC-)
CLK_P: HDMI.10 (CLK+), IC1.93 (RXC+)
D0_N: HDMI.9 (D0-), IC1.91 (RX0-)
D0_P: HDMI.7 (D0+), IC1.90 (RX0+)
D1_N: HDMI.6 (D1-), IC1.86 (RX1-)
D1_P: HDMI.4 (D1+), IC1.85 (RX1+)
D2_N: HDMI.3 (D2-), IC1.81 (RX2-)
D2_P: HDMI.1 (D2+), IC1.80 (RX2+)
DDC_SCL: HDMI.15 (SCL), IC2.1 (SCL), R5.2, SCL.1
DDC_SDA: HDMI.16 (SDA), IC2.3 (SDA), R4.2, SDA.1
DE: IC1.46 (DE), LCD.34 (DE)
G0: IC1.20 (OE8), LCD.13 (G0)
G1: IC1.21 (OE9), LCD.14 (G1)
G2: IC1.22 (OE10), LCD.15 (G2)
G3: IC1.23 (OE11), LCD.16 (G3)
G4: IC1.24 (OE12), LCD.17 (G4)
G5: IC1.25 (OE13), LCD.18 (G5)
G6: IC1.26 (OE14), LCD.19 (G6)
G7: IC1.27 (OE15), LCD.20 (G7)
GND: C1.1, C2.1, C3.1, C4.1, C5.1, C6.2, C7.1, C8.1, C9.1, HDMI.2 (D2S), HDMI.5 (D1S), HDMI.8 (D0S), HDMI.11 (CLKS), HDMI.17 (GND), IC1.1 (DFO), IC1.3 (ST), IC1.4 (PIXS), IC1.5 (DGND), IC1.19 (OGND), IC1.28 (OGND), IC1.39 (DGND), IC1.45 (OGND), IC1.58 (OGND), IC1.68 (DGND), IC1.76 (OGND), IC1.79 (AGND), IC1.83 (AGND), IC1.87 (AGND), IC1.89 (AGND), IC1.92 (AGND), IC1.98 (PGND), IC2.2 (GND), IC2.5 (WP), IC3.2 (GND), LCD.3 (GND), LCD.29 (GND), LCD.36 (GND), LCD2.5, LCD2.12, LCD2.38, R1.1, R6.1, R7A.1, RS1.1, RS2.1; also elsewhere on the board
HDMI_5V: HDMI.18 (+5V), HPWR.1
HDMI_DECT: HDMI.19 (HDP), R3.1
HSYNC: IC1.48 (HSYNC), LCD.32 (HSYNC)
LED+: C9.2, D6.C, IC3.5 (OUT), L+.1, LCD.2 (A)
LED-: 40MA.1, IC3.3 (FB), L-.1, LCD.1 (C), RS1.2
LX: D6.A, IC3.1 (LX), L1.2
unnamed: 40MA.2, RS2.2
unnamed: IC1.100 (OCK_INV), OCK-INV.1, R1.2
PDO: IC1.9 (PDO), LCD.31 (DISP), R2.1
PWM: IC3.4 (EN), R7A.2, R7B.1; also elsewhere on the board
R0: IC1.30 (OE16), LCD.5 (R0)
R1: IC1.31 (OE17), LCD.6 (R1)
R2: IC1.32 (OE18), LCD.7 (R2)
R3: IC1.33 (OE19), LCD.8 (R3)
R4: IC1.34 (OE20), LCD.9 (R4)
R5: IC1.35 (OE21), LCD.10 (R5)
R6: IC1.36 (OE22), LCD.11 (R6)
R7: IC1.37 (OE23), LCD.12 (R7)
SCDT: IC1.8 (SCDT), R2.2
SCL: SCL.2; also elsewhere on the board
SDA: SDA.2; also elsewhere on the board
SHLD3: HDMI.SHLD1 (SHLD), HDMI.SHLD2 (SHLD), HDMI.SHLD3 (SHLD), HDMI.SHLD4 (SHLD), R6.2
VSYNC: IC1.47 (VSYNC), LCD.33 (VSYNC)
X+: LCD.37 (X+), X+.1; also elsewhere on the board
X-: LCD.39 (X-), X-.1; also elsewhere on the board
Y+: LCD.40 (Y+), Y+.1; also elsewhere on the board
Y-: LCD.38 (Y-), Y-.1; also elsewhere on the board

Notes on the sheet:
I = 0.3V / RS
Digikey 490-5340-6-ND
Released under the Creative Commons Attribution Share-Alike License
http://creativecommons.org/licenses/by-sa/4.0/
Designed by Andreas Watterott (Watterott electronic)
Based on the work of Hubert Kahlert (HK-Datentechnik)
Developer Edition

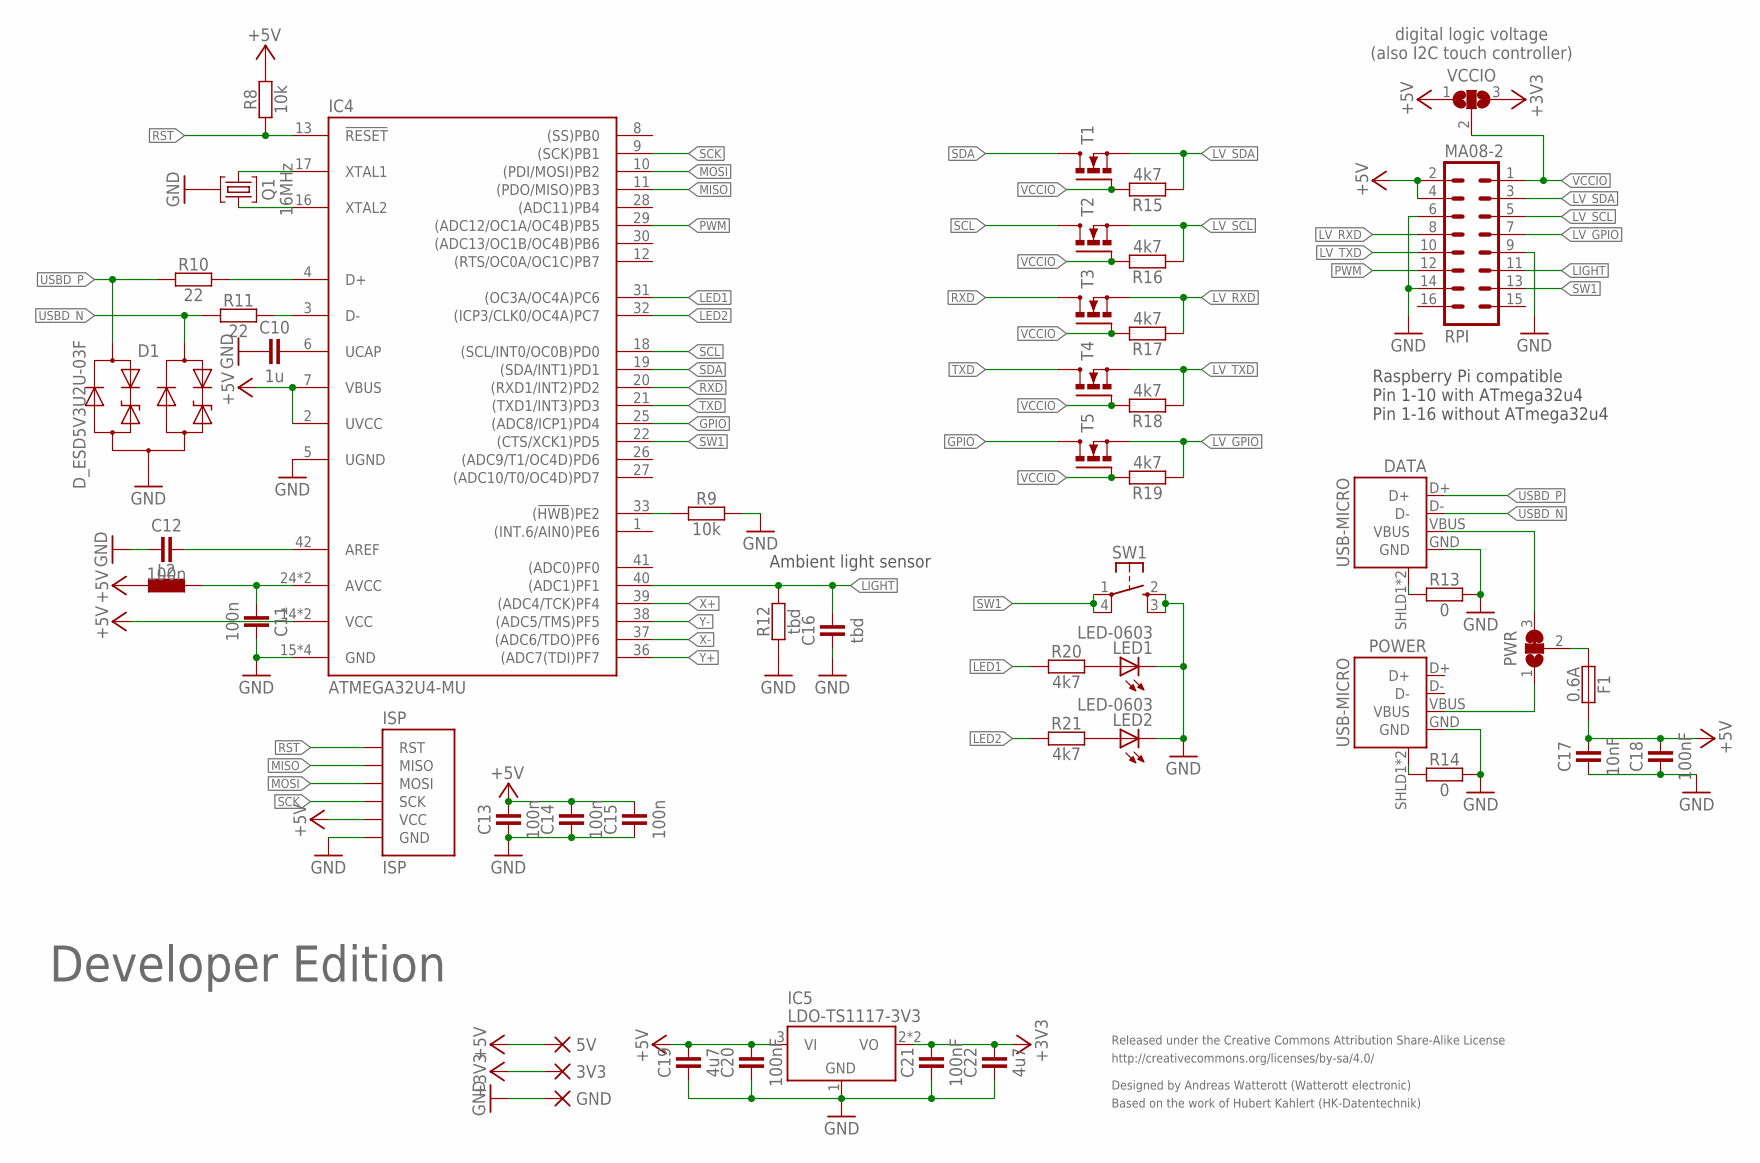
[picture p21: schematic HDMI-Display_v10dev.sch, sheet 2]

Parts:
3V3, 5V: PAD-1.27X2.54_NC
C10: 1u; R0402
C11, C12, C13, C14, C15: 100n; R0402
C16: tbd; R0402
C17: 10nF; R0402
C18, C20, C21: 100nF; R0402
C19, C22: 4u7; R0402
D1: D_ESD5V3U2U-03F; SOT723
DATA: USB-MICRO; USB-MICRO-10103594
F1: 0.6A; R0805
GND: PAD-1.27X2.54_NC
IC4: ATMEGA32U4-MU; QFN44
IC5: LDO-TS1117-3V3; SOT223
ISP: ISP
L2: INDUCTOR-0603; R0603
LED1, LED2: LED-0603; LED_0603
POWER: USB-MICRO; USB-MICRO-10103594
PWR: JUMPER3
Q1: 16MHz; CRYSTAL_32X13
R8, R9: 10k; R0402
R10, R11: 22; R0402
R12: tbd; R0402
R13, R14: 0; R0402
R15, R16, R17, R18, R19, R20, R21: 4k7; R0402
RPI: MA08-2
SW1: SW-TACTILE-TL3315; SW_TL3315N
T1, T2, T3, T4, T5: MOSFET-N-SOT23; SOT23
VCCIO: JUMPER3-NOCREAM; JUMPER3_NC

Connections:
+3V3: 3V3.1, C21.2, C22.2, IC5.2 (VO), IC5.4 (VO), VCCIO.3; also elsewhere on the board
+5V: 5V.1, C13.2, C14.2, C15.2, C17.2, C18.2, C19.2, C20.2, F1.1, IC4.2 (UVCC), IC4.7 (VBUS), IC4.14 (VCC), IC4.34 (VCC), IC5.3 (VI), ISP.VCC, L2.1, R8.2, RPI.2, RPI.4, VCCIO.1; also elsewhere on the board
AREF: C12.2, IC4.42 (AREF)
AVCC: C11.1, IC4.24 (AVCC), IC4.44 (AVCC), L2.2
D_N: IC4.3 (D-), R11.2
D_P: IC4.4 (D+), R10.2
GND: C10.1, C11.2, C12.1, C13.1, C14.1, C15.1, C16.1, C17.1, C18.1, C19.1, C20.1, C21.1, C22.1, D1.3 (A), DATA.GND, GND.1, IC4.5 (UGND), IC4.15 (GND), IC4.23 (GND), IC4.35 (GND), IC4.43 (GND), IC5.1 (GND), ISP.GND, LED1.C, LED2.C, POWER.GND, Q1.GND, R9.2, R12.1, R13.1, R14.1, RPI.6, RPI.9, RPI.14, SW1.2 (S1), SW1.3 (S2); also elsewhere on the board
GPIO: IC4.25 ((ADC8/ICP1)PD4), T5.3 (D)
HWB: IC4.33 ((!HWB!)PE2), R9.1
LED1: IC4.31 ((OC3A/OC4A)PC6), R20.1
LED2: IC4.32 ((ICP3/CLK0/OC4A)PC7), R21.1
LIGHT: C16.2, IC4.40 ((ADC1)PF1), R12.2, RPI.11
LV_GPIO: R19.1, RPI.7, T5.2 (S)
LV_RXD: R17.1, RPI.8, T3.2 (S)
LV_SCL: R16.1, RPI.5, T2.2 (S)
LV_SDA: R15.1, RPI.3, T1.2 (S)
LV_TXD: R18.1, RPI.10, T4.2 (S)
MISO: IC4.11 ((PDO/MISO)PB3), ISP.MISO
MOSI: IC4.10 ((PDI/MOSI)PB2), ISP.MOSI
unnamed: C10.2, IC4.6 (UCAP)
unnamed: F1.2, PWR.2
unnamed: LED1.A, R20.2
unnamed: LED2.A, R21.2
PWM: IC4.29 ((ADC12/OC1A/OC4B)PB5), RPI.12; also elsewhere on the board
RST: IC4.13 (!RESET), ISP.RST, R8.1
RXD: IC4.20 ((RXD1/INT2)PD2), T3.3 (D)
SCK: IC4.9 ((SCK)PB1), ISP.SCK
SCL: IC4.18 ((SCL/INT0/OC0B)PD0), T2.3 (D); also elsewhere on the board
SDA: IC4.19 ((SDA/INT1)PD1), T1.3 (D); also elsewhere on the board
SHLD1: DATA.SHLD1 (SHIELD), DATA.SHLD2 (SHIELD), R13.2
SHLD2: POWER.SHLD1 (SHIELD), POWER.SHLD2 (SHIELD), R14.2
SW1: IC4.22 ((CTS/XCK1)PD5), RPI.13, SW1.1, SW1.4 (P2)
TXD: IC4.21 ((TXD1/INT3)PD3), T4.3 (D)
USBD_N: D1.2 (C2), DATA.D-, R11.1
USBD_P: D1.1 (C1), DATA.D+, R10.1
VBUS: DATA.VBUS, PWR.3
VBUS_PWR: POWER.VBUS, PWR.1
VCCIO: R15.2, R16.2, R17.2, R18.2, R19.2, RPI.1, T1.1 (G), T2.1 (G), T3.1 (G), T4.1 (G), T5.1 (G), VCCIO.2
X+: IC4.39 ((ADC4/TCK)PF4); also elsewhere on the board
X-: IC4.37 ((ADC6/TDO)PF6); also elsewhere on the board
XTAL1: IC4.17 (XTAL1), Q1.2
XTAL2: IC4.16 (XTAL2), Q1.1
Y+: IC4.36 ((ADC7(TDI)PF7); also elsewhere on the board
Y-: IC4.38 ((ADC5/TMS)PF5); also elsewhere on the board

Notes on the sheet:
Ambient light sensor
Released under the Creative Commons Attribution Share-Alike License
http://creativecommons.org/licenses/by-sa/4.0/
Designed by Andreas Watterott (Watterott electronic)
Based on the work of Hubert Kahlert (HK-Datentechnik)
Raspberry Pi compatible Pin 1-10 with ATmega32u4 Pin 1-16 without ATmega32u4
Developer Edition
digital logic voltage (also I2C touch controller)

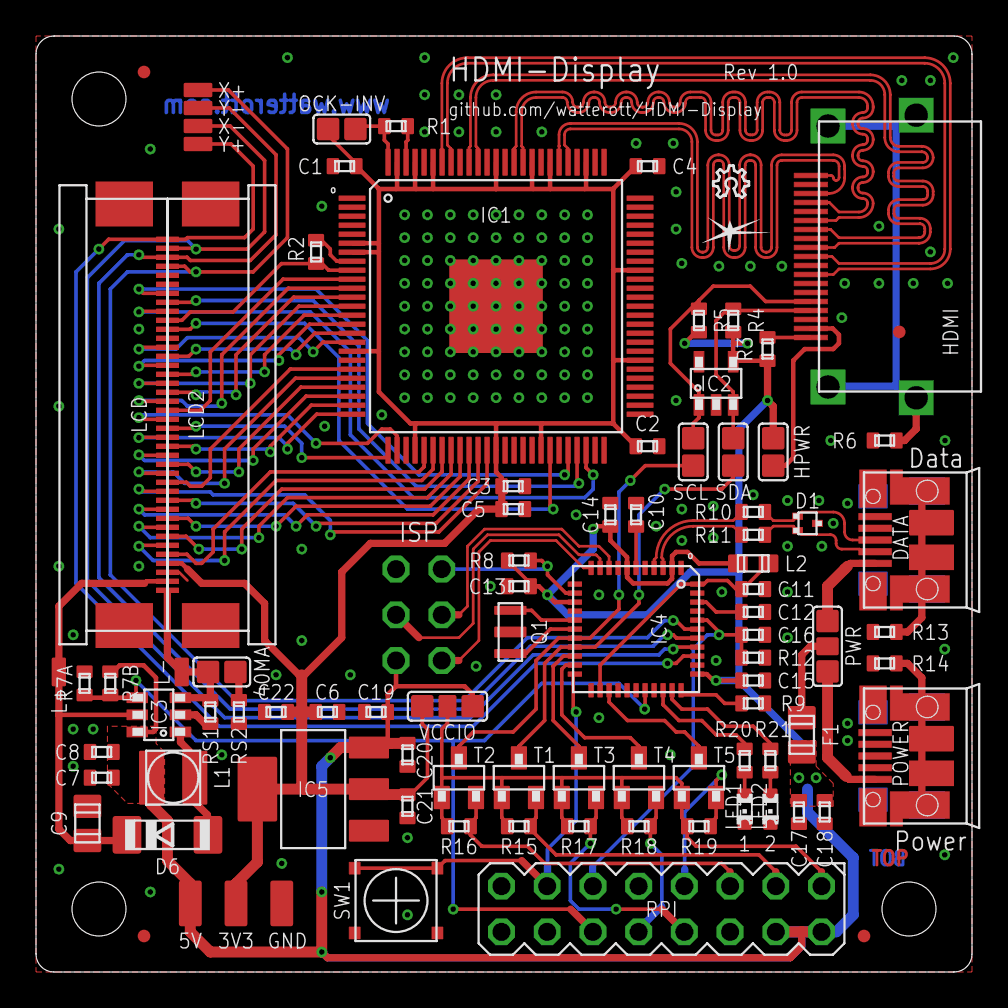
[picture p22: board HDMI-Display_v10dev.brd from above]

Board: 2 copper layers, 52.0 x 52.0 mm, 95 parts (1 on the bottom side), 92 nets.

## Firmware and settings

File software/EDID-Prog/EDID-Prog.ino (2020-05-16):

/*
  EDID I2C-EEPROM Programmer
  
  Note: SDA and SCL jumpers have to be closed.

  Example source code free to use.
  Further information: https://learn.watterott.com/license/
 */

//uncomment one display/EDID data
//#define EDID_480x272          // 480x272 (TFT043-3)
//#define EDID_800x480          // 800x480 (TFT050-3, HY5-LCD-HD, TFT070-4, HY7-LCD)
//#define EDID_800x480_720x480  // 800x480 (TFT050-3, HY5-LCD-HD, TFT070-4, HY7-LCD) with 720x480 (480p) fallback
//#define EDID_800x480HY        // 800x480 (HY070CTP-A, HY070CTP)
//#define EDID_1024x600         //1024x600 (HY070CTP-HD, HY101CTP)

#include <Wire.h>

#define EEPROMSIZE 256
#define EEPROMADDR 0x50

#define SW_1      (1<<5) //switch PD5
#define LED_1     (5)  //first LED PC6
#define LED_2     (13) //second LED PC7
#define BL_1      (9)  //PWM backlight boost converter PB5
#define BL_2      (10) //PWM display pin 35 PB6
#define AXM       (A1) //touch X- PF6
#define AXP       (A3) //touch X+ PF4
#define AYM       (A2) //touch Y- PF5
#define AYP       (A0) //touch Y+ PF7
#define INT       (4)  //touch interrupt PD4

const uint8_t PROGMEM eepromdata[128] =
{
#if defined EDID_480x272 //480x272 (TFT043-3)
  0x00,0xFF,0xFF,0xFF,0xFF,0xFF,0xFF,0x00,0x5C,0x34,0x01,0x00,0x01,0x00,0x00,0x00,
  0x01,0x19,0x01,0x03,0x81,0x00,0x00,0x00,0x0A,0x00,0x00,0x00,0x00,0x00,0x00,0x00,
  0x00,0x00,0x00,0x00,0x00,0x00,0x01,0x01,0x01,0x01,0x01,0x01,0x01,0x01,0x01,0x01,
  0x01,0x01,0x01,0x01,0x01,0x01,0xC4,0x09,0xE0,0x33,0x10,0x10,0x14,0x10,0x08,0x05,
  0x4A,0x00,0xE0,0x10,0x11,0x00,0x00,0x18,0x00,0x00,0x00,0xFC,0x00,0x48,0x44,0x4D,
  0x49,0x20,0x44,0x49,0x53,0x50,0x4C,0x41,0x59,0x0A,0x00,0x00,0x00,0x10,0x00,0x01,
  0x00,0x0A,0x00,0x0A,0x00,0x0A,0x0A,0x0A,0x0A,0x0A,0x20,0x0A,0x00,0x00,0x00,0x10,
  0x00,0x00,0x00,0x00,0x00,0x00,0x00,0x00,0x00,0x00,0x00,0x00,0x00,0x00,0x00,0x38

#elif defined EDID_800x480 //800x480 (TFT050-3, TFT070-4)
  0x00,0xFF,0xFF,0xFF,0xFF,0xFF,0xFF,0x00,0x5C,0x34,0x01,0x00,0x01,0x00,0x00,0x00,
  0x01,0x19,0x01,0x03,0x80,0x00,0x00,0x00,0x0A,0x00,0x00,0x00,0x00,0x00,0x00,0x00,
  0x00,0x00,0x00,0x00,0x00,0x00,0x01,0x01,0x01,0x01,0x01,0x01,0x01,0x01,0x01,0x01,
  0x01,0x01,0x01,0x01,0x01,0x01,0x1C,0x0C,0x20,0x80,0x30,0xE0,0x2D,0x10,0x28,0x30,
  0xD3,0x00,0x20,0xE0,0x31,0x00,0x00,0x18,0x00,0x00,0x00,0xFC,0x00,0x48,0x44,0x4D,
  0x49,0x20,0x44,0x49,0x53,0x50,0x4C,0x41,0x59,0x0A,0x00,0x00,0x00,0x10,0x00,0x00,
  0x00,0x00,0x00,0x00,0x00,0x00,0x00,0x00,0x00,0x00,0x00,0x00,0x00,0x00,0x00,0x10,
  0x00,0x00,0x00,0x00,0x00,0x00,0x00,0x00,0x00,0x00,0x00,0x00,0x00,0x00,0x00,0xB5

#elif defined EDID_800x480_720x480 //800x480 (TFT050-3, TFT070-4) with 720x480 (480p) fallback
  0x00,0xFF,0xFF,0xFF,0xFF,0xFF,0xFF,0x00,0x5C,0x34,0x01,0x00,0x01,0x00,0x00,0x00,
  0x01,0x19,0x01,0x03,0x80,0x00,0x00,0x00,0x0A,0x00,0x00,0x00,0x00,0x00,0x00,0x00,
  0x00,0x00,0x00,0x00,0x00,0x00,0x01,0x01,0x01,0x01,0x01,0x01,0x01,0x01,0x01,0x01,
  0x01,0x01,0x01,0x01,0x01,0x01,0x1C,0x0C,0x20,0x80,0x30,0xE0,0x2D,0x10,0x28,0x30,
  0xD3,0x00,0x20,0xE0,0x31,0x00,0x00,0x18,0x00,0x00,0x00,0xFC,0x00,0x48,0x44,0x4D,
  0x49,0x20,0x44,0x49,0x53,0x50,0x4C,0x41,0x59,0x0A,0x8C,0x0A,0xD0,0x6C,0x20,0xE0,
  0x1E,0x10,0x10,0x3E,0x96,0x00,0xD0,0xE0,0x21,0x00,0x00,0x18,0x00,0x00,0x00,0x10,
  0x00,0x00,0x00,0x00,0x00,0x00,0x00,0x00,0x00,0x00,0x00,0x00,0x00,0x00,0x00,0xF8

#elif defined EDID_800x480HY //800x480 display (HY070CTP-A)
  0x00,0xFF,0xFF,0xFF,0xFF,0xFF,0xFF,0x00,0x5C,0x34,0x01,0x00,0x01,0x00,0x00,0x00,
  0x01,0x19,0x01,0x03,0x80,0x00,0x00,0x00,0x0A,0x00,0x00,0x00,0x00,0x00,0x00,0x00,
  0x00,0x00,0x00,0x00,0x00,0x00,0x01,0x01,0x01,0x01,0x01,0x01,0x01,0x01,0x01,0x01,
  0x01,0x01,0x01,0x01,0x01,0x01,0xAA,0x0A,0x20,0x42,0x30,0xE0,0x2C,0x10,0x10,0x0A,
  0x51,0x04,0x20,0xE0,0x31,0x00,0x00,0x18,0x00,0x00,0x00,0xFC,0x00,0x48,0x44,0x4D,
  0x49,0x20,0x44,0x49,0x53,0x50,0x4C,0x41,0x59,0x0A,0x00,0x00,0x00,0x10,0x00,0x00,
  0x00,0x00,0x00,0x00,0x00,0x00,0x00,0x00,0x00,0x00,0x00,0x00,0x00,0x00,0x00,0x10,
  0x00,0x00,0x00,0x00,0x00,0x00,0x00,0x00,0x00,0x00,0x00,0x00,0x00,0x00,0x00,0x24

#elif defined EDID_1024x600 //1024x600 display (HY070CTP-HD)
  0x00,0xFF,0xFF,0xFF,0xFF,0xFF,0xFF,0x00,0x5C,0x34,0x01,0x00,0x01,0x00,0x00,0x00,
  0x01,0x19,0x01,0x03,0x80,0x00,0x00,0x00,0x0A,0x00,0x00,0x00,0x00,0x00,0x00,0x00,
  0x00,0x00,0x00,0x00,0x00,0x00,0x01,0x01,0x01,0x01,0x01,0x01,0x01,0x01,0x01,0x01,
  0x01,0x01,0x01,0x01,0x01,0x01,0xEC,0x13,0x00,0x80,0x40,0x58,0x2D,0x20,0x28,0x30,
  0xD3,0x00,0x00,0x58,0x42,0x00,0x00,0x18,0x00,0x00,0x00,0xFC,0x00,0x48,0x44,0x4D,
  0x49,0x20,0x44,0x49,0x53,0x50,0x4C,0x41,0x59,0x0A,0x00,0x00,0x00,0x10,0x00,0x00,
  0x00,0x00,0x00,0x00,0x00,0x00,0x00,0x00,0x00,0x00,0x00,0x00,0x00,0x00,0x00,0x10,
  0x00,0x00,0x00,0x00,0x00,0x00,0x00,0x00,0x00,0x00,0x00,0x00,0x00,0x00,0x00,0xFD

#else
  # error "Please set your display"
#endif
};

byte eeprom_read_byte(uint16_t addr)
{
  Wire.beginTransmission(EEPROMADDR);
  Wire.write((byte)addr);
  Wire.endTransmission();
  Wire.requestFrom(EEPROMADDR, 1);
  while(!Wire.available());
  return Wire.read();
}

void eeprom_write_byte(uint16_t addr, byte data)
{
  Wire.beginTransmission(EEPROMADDR);
  Wire.write((byte)addr);
  Wire.write((byte)data);
  Wire.endTransmission();
}

void setup()
{
  //set pin to input, because USB serial using this as an output (txled)
  DDRD &= ~SW_1;
  PORTD |= SW_1;
  //set analog pins to input
  pinMode(AXM, INPUT);
  pinMode(AXP, INPUT);
  pinMode(AYM, INPUT);
  pinMode(AYP, INPUT);
  pinMode(INT, INPUT);
  //set LEDs
  pinMode(LED_1, OUTPUT);
  digitalWrite(LED_1, HIGH); //on
  pinMode(LED_2, OUTPUT);
  digitalWrite(LED_2, LOW); //off
  //set backlight
  pinMode(BL_1, OUTPUT);
  digitalWrite(BL_1, LOW); //off
  pinMode(BL_2, OUTPUT);
  digitalWrite(BL_2, LOW); //off

  Serial.begin(9600); //9600 baud
  for(uint8_t port=0; !Serial.available() && (PIND & SW_1);) //wait for serial data or button press
  {
    if(Serial && port == 0)
    {
      port = 1;
      Serial.println(F("I2C-EEPROM WRITER"));
      Serial.println(F("Hit any key to start"));
    }
    digitalWrite(LED_2, LOW);
    delay(250);
    digitalWrite(LED_2, HIGH);
    delay(250);
  }

  Serial.println(F("Writing..."));
  digitalWrite(LED_1, LOW); //off
  digitalWrite(LED_2, HIGH); //on
  Wire.begin();
  for(uint16_t addr=0; addr < EEPROMSIZE; addr++)
  {
    byte b;
    if(addr < sizeof(eepromdata))
    {
      b = pgm_read_byte(eepromdata+addr);
    }
    else
    {
      b = 0xFF;
    }
    eeprom_write_byte(addr, b);
    delay(5);
  }
  Serial.println(F("Done."));

  Serial.println(F("Verifying..."));
  for(uint16_t addr=0; addr < EEPROMSIZE; addr++)
  {
    byte b, d;
    if (addr < sizeof(eepromdata))
    {
      b = pgm_read_byte(eepromdata+addr);
    }
    else
    {
      b = 0xFF;
    }
    d = eeprom_read_byte(addr);
    if (b != d)
    {
      Serial.print(F("failed at 0x"));
      Serial.println(addr, HEX);
      while(1);
    }
  }
  digitalWrite(LED_1, HIGH); //on
  digitalWrite(LED_2, HIGH); //on
  Serial.println(F("Done."));
}
 
void loop()
{
}

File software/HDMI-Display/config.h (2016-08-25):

#ifndef CONFIG_H
#define CONFIG_H

/*
 Watterott electronic Display Configurations:

  5" or 7" 800x480 with res. touch
    #define DISPLAY_TYPE    DISPLAY_800x480
    #define TOUCHPANEL_TYPE TOUCHPANEL_RESISTIVE //open jumpers TP_SDA, TP_SCL, TP_INT
    #define BACKLIGHT       BL_1
    #define BACKLIGHT_INV   0

  5" 800x480 with cap. touch (CPT)
    #define DISPLAY_TYPE    DISPLAY_800x480
    #define TOUCHPANEL_TYPE TOUCHPANEL_FT5X06 //close jumpers TP_SDA, TP_SCL, TP_INT
    #define BACKLIGHT       BL_2
    #define BACKLIGHT_INV   1

  7" 800x480 with cap. touch (CPT)
    #define DISPLAY_TYPE    DISPLAY_800x480HY
    #define TOUCHPANEL_TYPE TOUCHPANEL_FT5X06 //close jumpers TP_SDA, TP_SCL, TP_INT
    #define BACKLIGHT       BL_2
    #define BACKLIGHT_INV   1

  7" or 10" 1024x600 with cap. touch (CPT)
    #define DISPLAY_TYPE    DISPLAY_1024x600
    #define TOUCHPANEL_TYPE TOUCHPANEL_FT5X06 //close jumpers TP_SDA, TP_SCL, TP_INT
    #define BACKLIGHT       BL_2
    #define BACKLIGHT_INV   1

  HDMI-Adapter v1.0:
    Hardware modifications on TFTs with on-board Backlight Regulator needed.
    BACKLIGHT always BL_1 and BACKLIGHT_INV always 0
  HDMI-Adapter v1.1:
    Set Jumpers LED+ and LED- to 5V on TFTs with on-board Backlight Regulator.
*/

// --- Settings ---
#define DISPLAY_TYPE     DISPLAY_800x480 // DISPLAY_800x480 or DISPLAY_800x480HY or DISPLAY_1024x600
#define TOUCHPANEL_TYPE  TOUCHPANEL_RESISTIVE // TOUCHPANEL_NONE or TOUCHPANEL_RESISTIVE or TOUCHPANEL_FT5X06 or TOUCHPANEL_HY461X
#define BACKLIGHT        BL_1 // backlight pin (BL_1 or BL_2), BL_2 for HYxxxCTP
#define BACKLIGHT_INV    0    // backlight invert pwm (0 or 1), 1 for HYxxxCTP

#define BRIGHTNESS        255 // backlight brightness (0..255)
#define SCREENSAVERTIME   180 // seconds timeout (0...65535, 0=always on)
#define ORIENTATION         0 // orientation (0x1=invert x, 0x2=invert y, 0x4=swap axes, 0x8=map to screen coordinates)
#define LOOPTIME           16 // 16 ms = 60 Hz polling interval
#define TOUCHMAX        4095L // maximal touch/mouse position
#define USE_HIDPROJECT      0 // use HID-Project github.com/NicoHood/HID (0=no, 1=yes)
#define USE_WATCHDOG        0 // use watchdog timer
#define DEBUG               0 // set debug output level (0=nothing, 1=minimal...4)

#define QUOTE(name)     #name
#define STR(macro)      QUOTE(macro)
#define VERSION_STRING  "2.11"
#define INFO_STRING     "HDMI-Display\nVersion: " VERSION_STRING " (" __DATE__ ")\nInfo: https://github.com/watterott/HDMI-Display"

// Display Types
#define DISPLAY_480x272          1 //  480 x  272 (TFT043-3)
#define DISPLAY_640x480          2 //  640 x  480
#define DISPLAY_720x480          3 //  720 x  480
#define DISPLAY_800x320          4 //  800 x  320
#define DISPLAY_800x480          5 //  800 x  480 (TFT050-3, HY5-LCD-HD, HY050CTP-HD, TFT070-4, HY7-LCD)
#define DISPLAY_800x480_720x480  6 //  800 x  480 with 720x480 fallback
#define DISPLAY_800x480HY        7 //  800 x  480 (HY070CTP, HY070CTP-A)
#define DISPLAY_800x600          8 //  800 x  600
#define DISPLAY_1024x600         9 // 1024 x  600 (HY070CTP-HD, HY101CTP)
#define DISPLAY_1024x768        10 // 1024 x  768
#define DISPLAY_1280x720        11 // 1280 x  720
#define DISPLAY_1280x768        12 // 1280 x  768
#define DISPLAY_1280x800        13 // 1280 x  800
#define DISPLAY_1280x1024       14 // 1280 x 1024

// Touchpanel Types
#define TOUCHPANEL_NONE          1 // No Touchpanel present
#define TOUCHPANEL_RESISTIVE     2 // Resitive
#define TOUCHPANEL_FT5X06        3 // Capacitive FocalTech FT5X06
#define TOUCHPANEL_HY461X        4 // Capacitive Hycon HY461X

// Check Configurations
#if TOUCHPANEL_TYPE == TOUCHPANEL_NONE
  #undef SCREENSAVERTIME
  #define SCREENSAVERTIME 0
  #define TPC_X0 0    // not needed - touchpanel calibration x0
  #define TPC_X1 0    // not needed - touchpanel calibration x1
  #define TPC_Y0 0    // not needed - touchpanel calibration y0
  #define TPC_Y1 0    // not needed - touchpanel calibration y1
#elif TOUCHPANEL_TYPE == TOUCHPANEL_RESISTIVE
  #define TPC_X0 80   // touchpanel calibration x0
  #define TPC_X1 930  // touchpanel calibration x1
  #define TPC_Y0 825  // touchpanel calibration y0
  #define TPC_Y1 160  // touchpanel calibration y1
#elif TOUCHPANEL_TYPE == TOUCHPANEL_FT5X06
  #define TPC_X0 0    // not needed - touchpanel calibration x0
  #define TPC_X1 0    // not needed - touchpanel calibration x1
  #define TPC_Y0 0    // not needed - touchpanel calibration y0
  #define TPC_Y1 0    // not needed - touchpanel calibration y1
#elif TOUCHPANEL_TYPE == TOUCHPANEL_HY461X
  #define TPC_X0 0    // not needed - touchpanel calibration x0
  #define TPC_X1 0    // not needed - touchpanel calibration x1
  #define TPC_Y0 0    // not needed - touchpanel calibration y0
  #define TPC_Y1 0    // not needed - touchpanel calibration y1
#else
  #error "Please select a TOUCHPANEL_TYPE"
#endif
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

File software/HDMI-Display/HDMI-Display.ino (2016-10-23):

/*
  HDMI-Display Firmware
  ---------------------
  Written by Hubert Kahlert (HK-Datentechnik, www.hk-datentechnik.de)
  for Watterott electronic (www.watterott.com).
  
  USB-Mouse (Touchpanel)
    The Touchpanel acts as normal USB Mouse.
  
  USB-CDC Virtual COM-Port
    Settings:
      9600 8N1, Newline (NL)
    Commands:
      AT     -> Version information
      ATA    -> Backlight on
      ATH    -> Backlight off
      ATC    -> Touchpanel calibration
      ATR    -> Touchpanel reset/restart
      ATT    -> Touchpanel on
      ATU    -> Touchpanel off
      ATE    -> Write EDID to EEPROM (SDA+SCL closed)
      ATF    -> Write custom EDID to EEPROM (SDA+SCL closed)
      ATD    -> Load default settings
      ATSx?  -> Read register x
      ATSx=y -> Write register x (value y)
    Registers:
      0 -> X0 touch correction
      1 -> X1 touch correction
      2 -> Y0 touch correction
      3 -> Y1 touch correction
      4 -> Time for Screensaver in seconds (0...65535, 0=always on)
      5 -> Backlight (0...255)
      6 -> Orientation (0x1=invert x, 0x2=invert y, 0x4=swap axes, 0x8=map to screen coordinates)
      7 -> Screen width
      8 -> Screen height

  Resistive Touchpanel Calibration
    1. Hold down the switch and plug in the USB connector (power on).
    2. Press on the left edge (x axis) about 5s till the LED blinking changes.
    3. Press on the right edge (x axis) about 5s till the LED blinking changes.
    4. Press on the top edge (y axis) about 5s till the LED blinking changes.
    5. Press on the bottom edge (y axis) about 5s till the LED blinking changes.
    6. Calibration done.
 */

#include <avr/wdt.h>
#include "Arduino.h"
#include "HID.h"
#include "HDMI-Display.h"

Settings settings;
Backlight backlight;
TWI twi;
EDID edid;
#if USE_HIDPROJECT > 0
  //SingleAbsoluteMouse
#else
  Mouse_ Mouse;
#endif
#if TOUCHPANEL_TYPE == TOUCHPANEL_RESISTIVE
  Touchpanel_Resistive touchpanel;
#elif TOUCHPANEL_TYPE == TOUCHPANEL_FT5X06
  Touchpanel_FT5X06 touchpanel;
#elif TOUCHPANEL_TYPE == TOUCHPANEL_HY461X
  Touchpanel_HY461X touchpanel;
#else //if TOUCHPANEL_TYPE == TOUCHPANEL_NONE
  Touchpanel_None touchpanel;
#endif

bool isButtonPressed()
{
  bool rc;

#if ARDUINO < 150
  cli();
  SW_1_SETUP(); // switch pin to input, because USB serial uses it as output (txled)
  __asm__("nop\n\t");
  rc = SW_1_PRESSED();
  sei();
#else
  rc = SW_1_PRESSED();
#endif
  return rc;
}

void waitButtonReleased()
{
  while(isButtonPressed())
  {
    #if USE_WATCHDOG > 0
      wdt_reset();
    #endif
  }
}

void setup()
{
  // init pins
  SW_1_SETUP(); // switch pin to input, because USB serial uses it as output (txled)
  pinMode(LED_GREEN, OUTPUT);
  digitalWrite(LED_GREEN, HIGH);
  pinMode(LED_RED, OUTPUT);
  digitalWrite(LED_RED, LOW);

  // init watchdog timer
  #if USE_WATCHDOG > 0
    wdt_enable(WDTO_2S);
    wdt_reset();
  #endif

  // init serial port
  Serial.begin(9600); //set baudrate
  Serial.setTimeout(10); // wait 10ms for data (timeout)

  #if DEBUG > 3
    for(uint8_t port=0; !Serial.available() && !isButtonPressed();) // wait for serial data or button press
    {
      #if USE_WATCHDOG > 0
        wdt_reset();
      #endif
      if(Serial && port == 0)
      {
        port = 1;
        Serial.println(F("--- DEBUG BUILD ---"));
        Serial.println(F("Hit any key to start."));
      }
      digitalWrite(LED_RED, HIGH);
      delay(100);
      digitalWrite(LED_RED, LOW);
      delay(100);
    }
    Serial.println(F("Starting..."));
    Serial.flush();
  #endif

  twi.begin(); // init I2C (default speed: 100 kHz)

  #if USE_HIDPROJECT > 0
    SingleAbsoluteMouse.begin(); // init USB mouse (from HID-Project)
  #else
    Mouse.begin(); // init USB mouse
  #endif

  settings.setup(); // set default settings
  settings.load(); // load settings
  backlight.setup(); // init backlight
  touchpanel.setup(); // init touchpanel/touchcontroller

  // touchpanel calibration and EDID programming
  if(isButtonPressed())
  {
    // resistive touchpanel calibration
    digitalWrite(LED_GREEN, LOW);
    digitalWrite(LED_RED, HIGH);
    touchpanel.calibration();
    // write EDID to external EEPROM
    if(!edid.writeEDID(DISPLAY_TYPE))
    {
      //error blinking
      #if USE_WATCHDOG > 0
        wdt_reset();
      #endif
      digitalWrite(LED_RED, LOW);
      delay(250);
      digitalWrite(LED_RED, HIGH);
      delay(250);
    }
  }

  digitalWrite(LED_GREEN, HIGH);
  digitalWrite(LED_RED, LOW);
}

void sendAck()
{
  Serial.println(F("OK"));
}

void sendNack()
{
  Serial.println(F("ERROR"));
}

void ATCommandsLoop()
{
  int reg;

  #if USE_WATCHDOG > 0
    wdt_reset();
  #endif

  if(Serial.find((char*)"AT"))
  {
    digitalWrite(LED_RED, HIGH);

    uint8_t b = (uint8_t)Serial.read();
    switch(b)
    {
      case '\n': // info
      case '\r':
        Serial.println(F(INFO_STRING));
        Serial.println(F("Touch: " STR(TOUCHPANEL_TYPE)));
        Serial.print(F("TFT: "));
        Serial.print(settings.data.screenWidth);
        Serial.print("x");
        Serial.println(settings.data.screenHeight);
        sendAck();
        break;

      case 'A': // backlight on
        backlight.on();
        sendAck();
        break;

      case 'H': // backlight off
        backlight.off();
        sendAck();
        break;

      case 'C': // touchpanel calibration
        touchpanel.calibration();
        sendAck();
        break;

      case 'R': // touchpanel reset/restart
        touchpanel.setup();
        sendAck();
        break;

      case 'T': // touchpanel on
        touchpanel.on();
        sendAck();
        break;

      case 'U': // touchpanel off
        touchpanel.off();
        sendAck();
        break;

      case 'E': // write EDID to external EEPROM
        if(edid.writeEDID(DISPLAY_TYPE))
          sendAck();
        else
          sendNack();
        break;

      case 'F': // write custom EDID to external EEPROM
        if(edid.writeEDID(0))
          sendAck();
        else
          sendNack();
        break;

      case 'D': // load default settings
        settings.setup();
        sendAck();
        break;
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

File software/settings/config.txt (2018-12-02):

# Raspberry Pi Settings - /boot/config.txt
# https://www.raspberrypi.org/documentation/configuration/config-txt/video.md
# https://elinux.org/RPiconfig
# hdmi_cvt=<width> <height> <framerate> <aspect> <margins> <interlaced> <reduced_blanking>
# hdmi_timing=<h_active_pixels> <h_sync_polarity> <h_front_porch> <h_sync_pulse> <h_back_porch> <v_active_lines> <v_sync_polarity> <v_front_porch> <v_sync_pulse> <v_back_porch> <v_sync_offset_a> <v_sync_offset_b> <pixel_rep> <framerate> <interlaced> <pixel_freq> <aspect>
# aspect ratio: 1=4:3, 2=14:9, 3=16:9, 4=5:4, 5=16:10, 6=15:9, 7=21:9, 8=64:27

# set current over USB to 1.2A (Pi1 A+/B+, Pi2, Pi3)
max_usb_current=1

# overscan to adjust image position
overscan_left=0
overscan_right=0
overscan_top=0
overscan_bottom=0

# HDMI config
hdmi_drive=1
hdmi_ignore_edid=0xa5000080
hdmi_group=2
hdmi_mode=87

# uncomment for 480x272 display (TFT043-3)
#hdmi_timings=480 0 1 41 2 272 0 2 10 2 0 0 0 60 0 9009000 3

# uncomment for 800x480 display (TFT050-3, HY5-LCD-HD, HY050CTP-HD, TFT070-4, HY7-LCD)
#hdmi_cvt=800 480 60 6 0 0 0
#can also be used: hdmi_timings=800 0 40 48 88 480 0 13 3 32 0 0 0 60 0 31000000 6

# uncomment for 800x480 display (HY070CTP, HY070CTP-A)
#hdmi_timings=800 0 16 10 40 480 0 21 1 22 0 0 0 60 0 27300000 6
#can also be used: hdmi_timings=800 0 16 16 34 480 0 21 1 22 0 0 0 60 0 27300000 6
# for Kodi/XBMC, needs about 2 minutes after booting to stabilize the image
#hdmi_timings=800 0 16 6 44 480 0 21 1 22 0 0 0 60 0 27300000 6

# uncomment for 1024x600 display (HY070CTP-HD, HY101CTP)
#hdmi_cvt=1024 600 60 3 0 0 0

# 0 degrees - normal
#display_rotate=0
# 90 degrees
#display_rotate=1
# 180 degrees
#display_rotate=2
# 270 degrees
#display_rotate=3
# horizontal flip
#display_rotate=0x10000
# vertical flip
#display_rotate=0x20000

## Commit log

2015-01-10 added layout and schematics
    [HDMI-Display_v10dev.brd, HDMI-Display_v10dev.sch]
2015-01-10 added EDID data
    [config.txt]
2015-01-11 updated docu and added examples
    [config.txt]
2015-01-11 updated readme and docu
    [config.txt]
2015-01-11 updated schematics
2015-01-28 updated layout and schematics
    [HDMI-Display_v10.brd, HDMI-Display_v10.sch]
2015-01-29 support for Arduino 1.5
2015-01-29 updated docu
    [config.txt]
2015-02-09 added FT5x06 (capacitive touch controller) support
2015-02-10 updated firmware for Arduino v1.6
2015-02-10 updated HY070CTP-A EDID
    [config.txt]
2015-02-12 touchpanel and screensaver bugfix
    [HDMI-Display.ino, backlight.cpp, config.h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]
2015-02-21 added axes invertation+swapping and touchpanel detection
    [HDMI-Display.ino, config.h, touchpanel_FT5x06.cpp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]
2015-02-22 bugfix: orientation not set on startup
    [HDMI-Display.ino]
2015-02-26 updated backlight current
2015-03-13 updated board support package
2015-04-08 updated schematics/display info
2015-07-02 typo fix
    [config.txt]
2015-08-19 added 2nd pwm pin (pcb rev 1.1)
2015-08-21 changed path structure
    [HDMI-Display_v10.brd, HDMI-Display_v10.sch, HDMI-Display_v10dev.brd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]
2015-08-26 added rev 1.1 schematics and layout
    [HDMI-Display_v11.brd, HDMI-Display_v11.sch]
2015-09-11 updated schematics and docu
    [HDMI-Display_v11.brd, HDMI-Display_v11.sch]
2015-09-24 minor changes and bugfix in backlight.cpp
    [backlight.cpp, config.h, edid.cpp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]
2015-12-20 rewrite to use own TWI/I2C functions
2016-02-04 updated schematics and layout
    [HDMI-Display_v11.brd, HDMI-Display_v11.sch]
2016-04-04 added offset for capacitive touchpanels
2016-04-12 updated pin info
    [HDMI-Display_v11.brd]
2016-07-29 write EDID, when button is pressed on startup set backlight brightness on change
2016-08-21 check touch controller at about 8Hz
2016-08-25 I2C/TWI frequency bugfix
2016-10-23 only red LED on during EEPROM programming
2017-04-11 added rev 1.2
    [HDMI-Display_v12.brd, HDMI-Display_v12.sch]
2017-07-30 moved docu to docs
    [config.txt]
2018-01-30 moved files
    [config.txt]
2018-05-01 added rev 1.3
    [HDMI-Display_v13.brd, HDMI-Display_v13.sch]
2018-12-02 updated settings
    [config.txt]
